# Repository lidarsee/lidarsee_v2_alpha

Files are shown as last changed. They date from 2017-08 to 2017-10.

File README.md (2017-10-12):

# LIDARsee v2 Hardware 

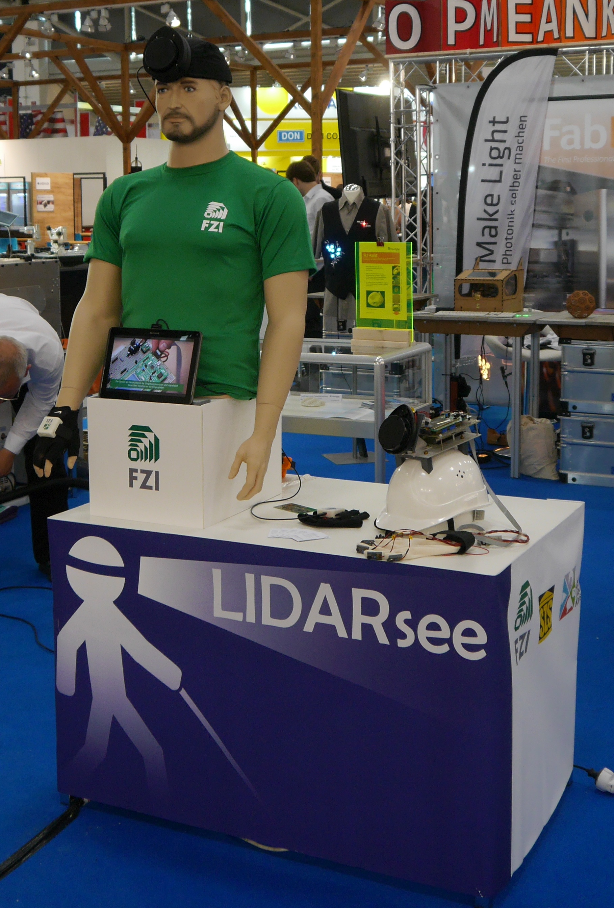
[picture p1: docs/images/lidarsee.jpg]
lidarsee


A good summary of the _Neato XV-11 LIDAR module_ can be found at:  
http://blog.tkjelectronics.dk/2014/08/handheld-xv-11-lidar-with-stm32f429-and-matlab/

## License
**Hardware license**: Creative Commons CC0
https://creativecommons.org/publicdomain/zero/1.0/legalcode

**Software license**: MIT License

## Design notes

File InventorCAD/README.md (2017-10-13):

# LIDARsee v2 Enclosure

Design is done in _Autodesk Inventor 2016_

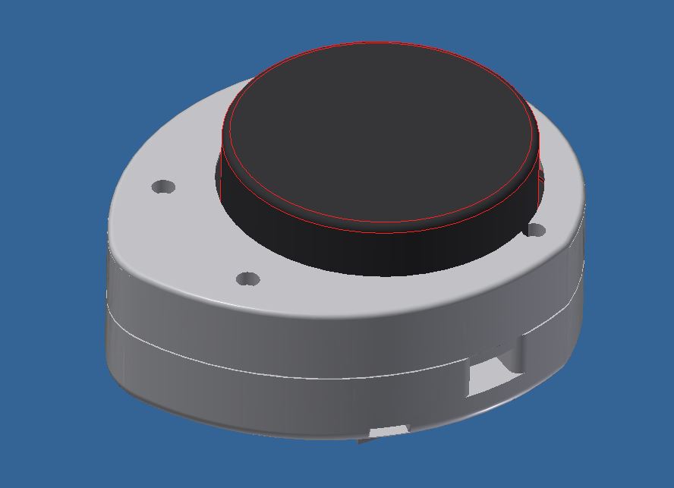
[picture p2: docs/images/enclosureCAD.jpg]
enclosure CAD


/ stp files for 3D printing, we used standard ABS and a common FDM-3D-Printer (reprap) for all parts of the construction

* _Lidarsee_v2.iam_ - main assembly
* _Lidar.ipt_ and _Lidar_v2.ipt_ are rough models of the _XV-11 LIDAR Module_
* There is also a mockup of the PCB available

## Brass Insert Nut
For the installation we used brass insert nuts which we mounted by using an old soldering iron. 

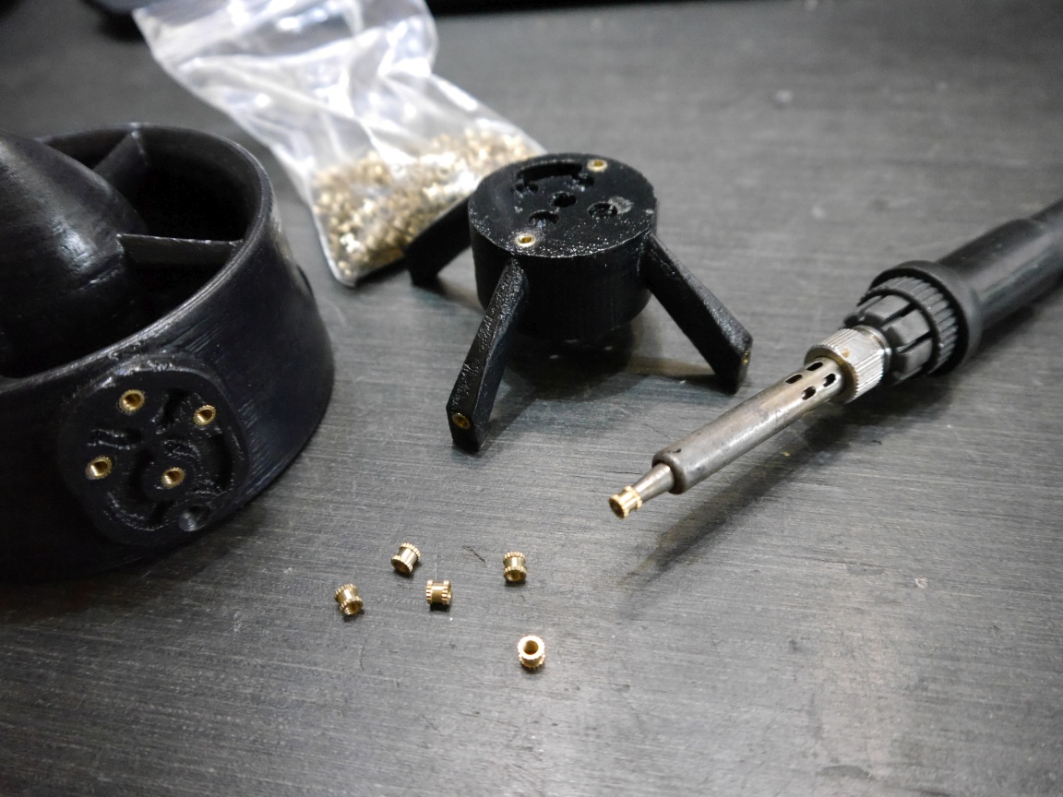
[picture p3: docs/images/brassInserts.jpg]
brassinsertnut


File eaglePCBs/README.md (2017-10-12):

# lidarsee_v2_hardware
Motherboard_STM32F405RG_r1 ist the mainboard for the head unit. 

### Features
* XV-11 lidar compatible
* STM32F405 microprocessor
* ESP32 WiFi/bluetooth-module
* Single cell lipo power supply
* MPU6050 IMU
* We used a single cell 2500mAh LiPo battery

### To Do
* Rework of the LiPo Boost converter (larger inductor?)
* IMU not tested, it is recommended to use an external IMU connected to the I2C port. Soldering the IMU by hand is quite difficult and there are a lot of cheap reliable breakout boards available. For example the BNO055 sensor also delivers easy-to-use Euler's Angles.
* Using parts that can be soldered by hand easierly

## Wiring

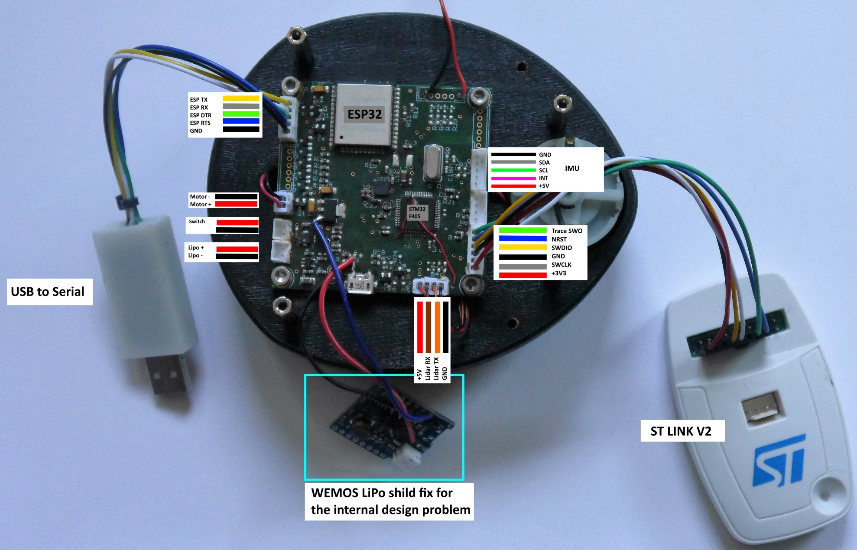
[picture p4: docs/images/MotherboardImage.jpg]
assemblyMainbaord


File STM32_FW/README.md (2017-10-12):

# lidarsee_v2_alpha STM32 Firmware

We used the _CooCox CoIDE_ for the STM32 development. A free version can be downloaded at: http://www.coocox.org/

We highly recommend to use the version 1.7.8 and _not_ to use the 2.xx beta or any 2.x Version since the compatibility is very poor. 

For programming and debugging we used a ST-Link-V2 in SWD-Mode.

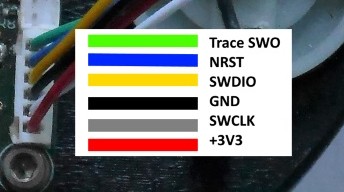
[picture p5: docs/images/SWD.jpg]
SWD


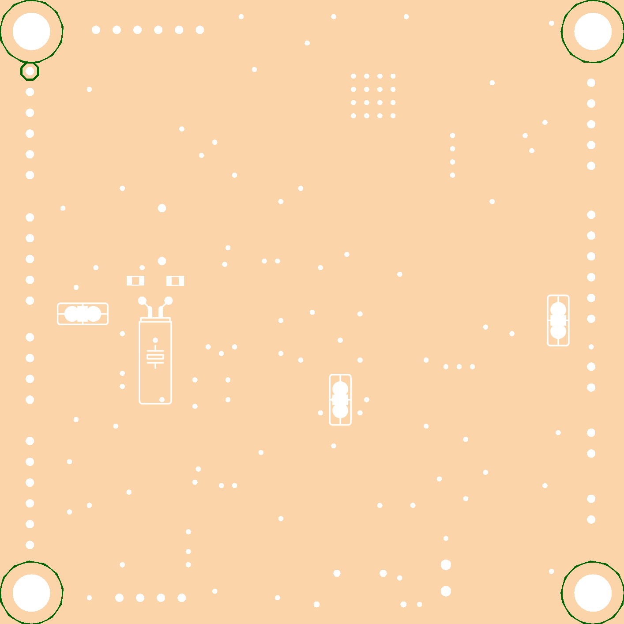
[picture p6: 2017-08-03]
InventorCAD/lidarsee/Motherboard_STM32F405RG_BOTTOM.png

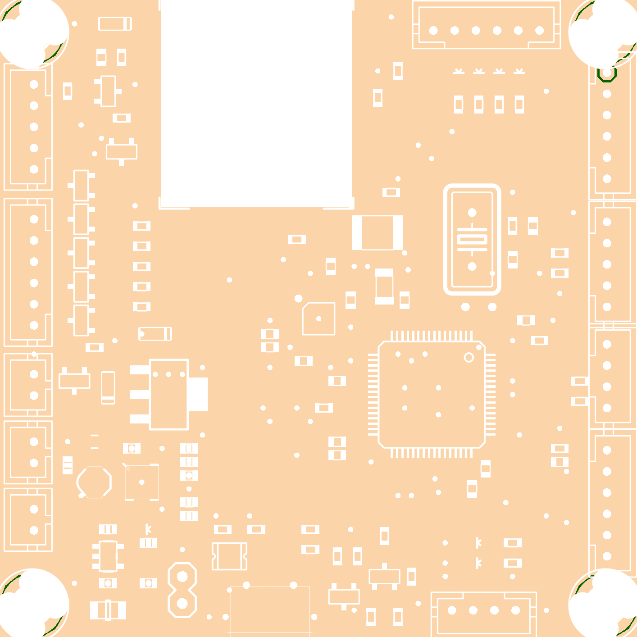
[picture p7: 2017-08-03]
InventorCAD/lidarsee/Motherboard_STM32F405RG_TOP.png

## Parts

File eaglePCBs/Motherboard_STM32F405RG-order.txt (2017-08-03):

Order list for C:/Users/ahoel/Dropbox/eagle/lidarsee/Motherboard_STM32F405RG.sch
Exported from EAGLE with DesignLink

Anzahl	Value	Package	Ordercode	Hersteller	Herstellercode	Verfügbarkeit	Preis (ab)	Beschreibung
1	10uF	1206	1288264	KEMET	C1206C106K8RACTU	13981	0.134	KEMET - C1206C106K8RACTU - KONDENSATOR, MLCC, X7R, 10UF, 10V, 1206
2	0.1uF	0603-CAP	431989	YAGEO (PHYCOMP)	CC0603MRY5V9BB104	113263	0.0076	YAGEO (PHYCOMP) - CC0603MRY5V9BB104 - KONDENSATOR, MLCC, Y5V, 100NF, 50V, 0603
1	100n	0805	1288255	KEMET	C0603C104K5RACTU	587750	0.0064	KEMET - C0603C104K5RACTU - KONDENSATOR, MLCC, X7R, 100NF, 50V, 0603
9	100n	C0603	1288255	KEMET	C0603C104K5RACTU	587750	0.0064	KEMET - C0603C104K5RACTU - KONDENSATOR, MLCC, X7R, 100NF, 50V, 0603
2	2.2µF 6.3V	C0603	1288257	KEMET	C0603C225K9PACTU	8038	0.0246	KEMET - C0603C225K9PACTU - KONDENSATOR, MLCC, X5R, 2.2UF, 6.3V 0603
2	4.7uF	0603-CAP	1572625	KEMET	C0603C475K8PACTU	55850	0.0523	KEMET - C0603C475K8PACTU - KONDENSATOR, MLCC, X5R, 4.7UF, 10V, 0603
1	10u 10V	C1206	1288264	KEMET	C1206C106K8RACTU	13981	0.134	KEMET - C1206C106K8RACTU - KONDENSATOR, MLCC, X7R, 10UF, 10V, 1206
2	27p	C0603	722017	YAGEO (PHYCOMP)	CC0603JRNPO9BN270	13342	0.0072	YAGEO (PHYCOMP) - CC0603JRNPO9BN270 - KONDENSATOR MLCC C0G/NP0 27PF 50V 0603
2	10p	C0603	317202	AVX	06035A102JAT2A	125356	0.0107	AVX - 06035A102JAT2A - KONDENSATOR, MLCC, C0G/NP0, 1NF 50V 0603
1	1µ	C0603	1658870	AVX	0603YC105KAT2A	27884	0.018	AVX - 0603YC105KAT2A - KONDENSATOR, MLCC, X7R, 1UF, 16V, 0603
1	10n	C0603	722236	YAGEO (PHYCOMP)	CC0603KRX7R9BB103	34686	0.0066	YAGEO (PHYCOMP) - CC0603KRX7R9BB103 - KONDENSATOR, MLCC, X7R, 10NF, 50V, 0603
3	33µF	A/3216-18W	2333095	AVX	TPSA336M006R0600	3018	0.193	AVX - TPSA336M006R0600 - TANTALKONDENSATOR, 33UF, 6.3V, BAUFORM A
1	2.2n	C0603	722194	YAGEO (PHYCOMP)	CC0603KRX7R9BB222	7636	0.0083	YAGEO (PHYCOMP) - CC0603KRX7R9BB222 - KONDENSATOR, MLCC, X7R, 2.2NF, 50V, 0603
7	red	LED-0603	1226390	OSRAM	LSQ976-Z	15931	0.0358	OSRAM - LSQ976-Z - LED, SMD ROT
1	1210L010	1210L	1822206	LITTELFUSE	1210L010WR	5849	0.172	LITTELFUSE - 1210L010WR - SICHERUNG, PTC, 1210, 0.1A
4	MOUNT-PAD-ROUND3.6	3,6-PAD	unknown					
1	STM32F40X	LQFP64	2064363	STMICROELECTRONICS	STM32F405RGT6	9718	6.18	STMICROELECTRONICS - STM32F405RGT6 - IC,MCU, 32BIT, 1MB FLASH, 64LQFP
1	LD1117ASTR	SOT223	1652366	ON SEMICONDUCTOR	NCP1117ST33T3G	6296	0.127	ON SEMICONDUCTOR - NCP1117ST33T3G - LINEARSPANNUNGSREGLER
1	IN	1X02	9491856	JST (JAPAN SOLDERLESS TERMINALS)	B2B-PH-K-S(LF)(SN)	446666	0.0581	JST (JAPAN SOLDERLESS TERMINALS) - B2B-PH-K-S(LF)(SN) - STECKER,OBEN EING,2KONT
1	4.7uH, 1.2A	CDRH2D09	2219271	MURATA	LQH3NPN4R7MJ0L	838	0.106	MURATA - LQH3NPN4R7MJ0L - LEISTUNGSINDUKTIVITÄT, 4.7UH, +/-30%
1		L1812	unknown					
2		JST-PH4	9492437	JST (JAPAN SOLDERLESS TERMINALS)	B4B-PH-K-S(LF)(SN)	145775	0.0844	JST (JAPAN SOLDERLESS TERMINALS) - B4B-PH-K-S(LF)(SN) - STECKER,OBEN EING,4KONT
2	JST-PH5	JST-PH5	9492445	JST (JAPAN SOLDERLESS TERMINALS)	B5B-PH-K-S(LF)(SN)	37245	0.105	JST (JAPAN SOLDERLESS TERMINALS) - B5B-PH-K-S(LF)(SN) - STECKER,OBEN EING,5KONT
4		JST-PH6	9492453	JST (JAPAN SOLDERLESS TERMINALS)	B6B-PH-K-S(LF)(SN)	120187	0.121	JST (JAPAN SOLDERLESS TERMINALS) - B6B-PH-K-S(LF)(SN) - STECKER,OBEN EING,6KONT
3		JST-PH2	9491856	JST (JAPAN SOLDERLESS TERMINALS)	B2B-PH-K-S(LF)(SN)	446666	0.0581	JST (JAPAN SOLDERLESS TERMINALS) - B2B-PH-K-S(LF)(SN) - STECKER,OBEN EING,2KONT
6	IRLML6344	SOT23	1857299	INFINEON	IRLML6344TRPBF	37543	0.104	INFINEON - IRLML6344TRPBF - MOSFET, N-KANAL, 30V, 5A, SOT23
1	8MHz	HC18U-V	1666997	MULTICOMP	HC49S-8-30-50-70-30-ATF	7738	0.228	MULTICOMP - HC49S-8-30-50-70-30-ATF - QUARZ, HC-49/S, 8.0MHZ
1	32768	TC38H	1457085	CITIZEN FINETECH MIYOTA	CFS206 32.768KDZB-UB	18815	0.113	CITIZEN FINETECH MIYOTA - CFS206 32.768KDZB-UB - QUARZ, UHR, 32.768KHZ, ZYLINDER, 6PF
1	1.2M	0603-RES	2073340	MULTICOMP	MCMR06W2004FTL	6247	0.0029	MULTICOMP - MCMR06W2004FTL - KERAMIKWIDERSTAND, 2M, 1%, 0.1W, 0603
1	10k	0603-RES	2073349	MULTICOMP	MCMR06X1002FTL	70119	0.0027	MULTICOMP - MCMR06X1002FTL - KERAMIKWIDERSTAND, 10K, 1%, 0.1W, 0603
1	2M	0603-RES	1811595	KOA SPEER ELECTRONICS	RK73H1JTTD1204F	6769	0.0134	KOA SPEER ELECTRONICS - RK73H1JTTD1204F - DICKSCHICHTWIDERSTAND 1M2 1% 0.1W 0603
2	220k	0603-RES	1576314	MULTICOMP	MCHP03W8F2203T5E	57056	0.0059	MULTICOMP - MCHP03W8F2203T5E - DICKSCHICHTWIDERST. 220K 1% 0.125W 0603
1	2k	0603-RES	9238522	YAGEO (PHYCOMP)	RC0603FR-072K2L.	90932	0.0040	YAGEO (PHYCOMP) - RC0603FR-072K2L. - DICKSCHICHTWIDERSTAND 2K2 1% 0.1W 0603
14	10	R0603	1469751	VISHAY	CRCW060310R0FKEA	93997	0.0055	VISHAY - CRCW060310R0FKEA - DICKSCHICHTWIDERSTAND 10R 1% 0.1W 0603
1	470	0603-RES	1576273	MULTICOMP	MCHP03W8F4700T5E	19878	0.0057	MULTICOMP - MCHP03W8F4700T5E - DICKSCHICHTWIDERST. 470R 1% 0.125W 0603
1	1M	R0603	1469746	VISHAY	CRCW06031M00FKEA	65750	0.0055	VISHAY - CRCW06031M00FKEA - DICKSCHICHTWIDERSTAND 1M 1% 0.1W 0603
3	22	R0603	1469781	VISHAY	CRCW060322R0FKEA	11239	0.0055	VISHAY - CRCW060322R0FKEA - DICKSCHICHTWIDERSTAND 22R 1% 0.1W 0603
5	33k	R0603	1469801	VISHAY	CRCW060333K0FKEA	14795	0.0055	VISHAY - CRCW060333K0FKEA - DICKSCHICHTWIDERSTAND 33K 1% 0.1W 0603
1	10k	R0603	2073349	MULTICOMP	MCMR06X1002FTL	70119	0.0027	MULTICOMP - MCMR06X1002FTL - KERAMIKWIDERSTAND, 10K, 1%, 0.1W, 0603
1	1k5	R0603	2073391	MULTICOMP	MCMR06X1501FTL	5289	0.0027	MULTICOMP - MCMR06X1501FTL - KERAMIKWIDERSTAND, 1K5, 1%, 0.1W, 0603
1	1k	R0603	1469740	VISHAY	CRCW06031K00FKEA	230207	0.0055	VISHAY - CRCW06031K00FKEA - DICKSCHICHTWIDERSTAND 1K 1% 0.1W 0603
1	47k	R0603	1469811	VISHAY	CRCW060347K0FKEA	12994	0.0055	VISHAY - CRCW060347K0FKEA - DICKSCHICHTWIDERSTAND 47K 1% 0.1W 0603
1	15k	R0603	1469758	VISHAY	CRCW060315K0FKEA	21335	0.0055	VISHAY - CRCW060315K0FKEA - DICKSCHICHTWIDERSTAND 15K 1% 0.1W 0603
1	22k	R0603	1527541	TE CONNECTIVITY / NEOHM	CPF0603F4K22C1	995	0.0192	TE CONNECTIVITY / NEOHM - CPF0603F4K22C1 - DÜNNSCHICHTWIDERST. 4K22 1% 0.063W 0603
8	12k	R0603	1170832	MULTICOMP	MC0063W060312K8	53482	0.0020	MULTICOMP - MC0063W060312K8 - DICKSCHICHTWIDERSTAND 2K8 1% 0.063W 0603
3		SJ_2	unknown					
4		SOT23-BEC	1081223	NEXPERIA	BC817,215	24559	0.019	NEXPERIA - BC817,215 - TRANSISTOR, NPN, 45V, SOT-23
1	MPU-9250	LEAD-QFN24	1864742	INVENSENSE	MPU-6050	2496	5.65	INVENSENSE - MPU-6050 - GYRO/BESCHL.MESSER, 6ACHSEN, I2C, QFN-24
1	MICRO-USB-RECEPTACLE47589-0001	47589-0001	1568023	MOLEX	47589-0001	8109	0.315	MOLEX - 47589-0001 - MICRO-USB-2.0-BUCHSE, TYP AB, SMD
1	ESP-WROOM-03	ESP-WROOM-03	unknown					
1	MCP73831	SOT23-5	1332158	MICROCHIP	MCP73831T-2ACI/OT	28596	0.394	MICROCHIP - MCP73831T-2ACI/OT - LI-ION/LI-POLY LADE CONTROLLER
1	TPS61200	QFN-10_PAD	1471238	TEXAS INSTRUMENTS	TPS61200DRCT	412	1.87	TEXAS INSTRUMENTS - TPS61200DRCT - WANDLER,BOOST SYNCH, 1.5A, SMD

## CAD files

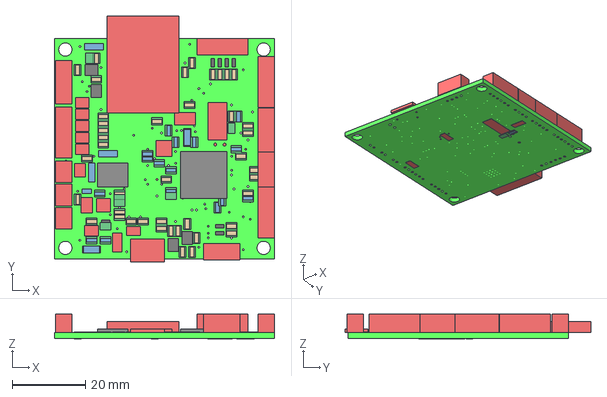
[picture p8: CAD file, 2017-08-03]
InventorCAD/lidarsee/Motherboard_STM32F405RG_simpel.STEP
60.0 x 67.0 x 6.67 mm

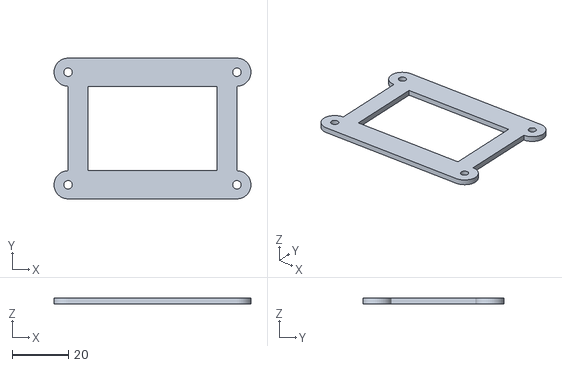
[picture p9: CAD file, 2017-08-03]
InventorCAD/lidarsee/stl/templateMount_0.stl
70.0 x 50.0 x 2.00

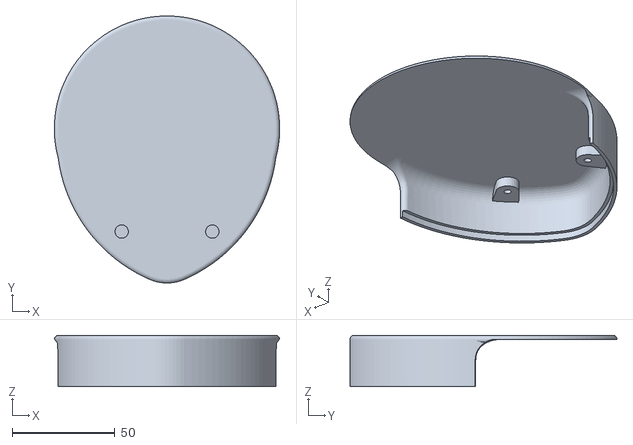
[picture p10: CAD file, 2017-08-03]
InventorCAD/lidarsee/stl/LidarseeCase_C_0.stl
109.5 x 129.7 x 25.0

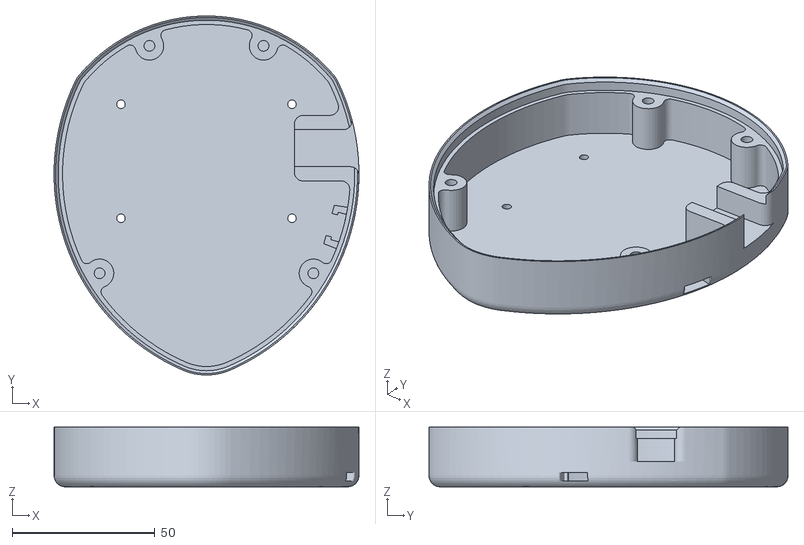
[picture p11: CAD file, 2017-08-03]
InventorCAD/lidarsee/stl/LidarseeCase_v2_C_0.stl
107.0 x 126.0 x 21.0

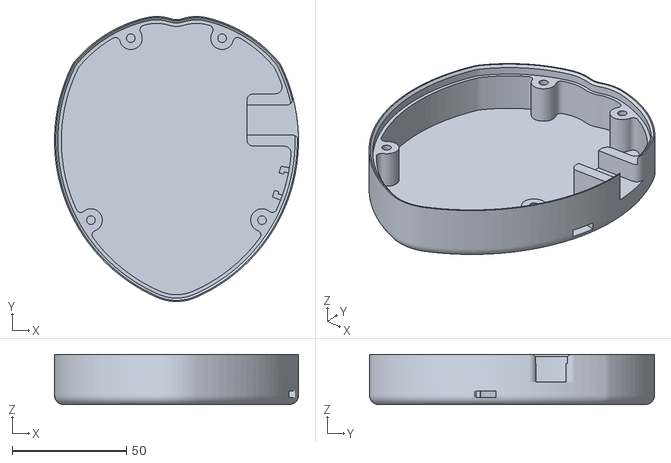
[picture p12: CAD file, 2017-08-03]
InventorCAD/lidarsee/stl/LidarseeCase_B_0.stl
107.0 x 125.0 x 22.0

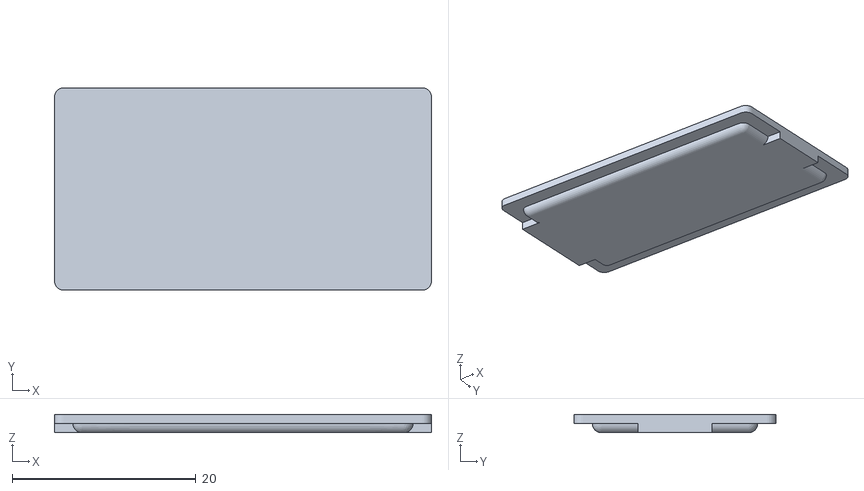
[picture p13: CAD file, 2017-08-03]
InventorCAD/lidarsee/stl/USB_case_B_0.stl
41.0 x 22.0 x 2.00

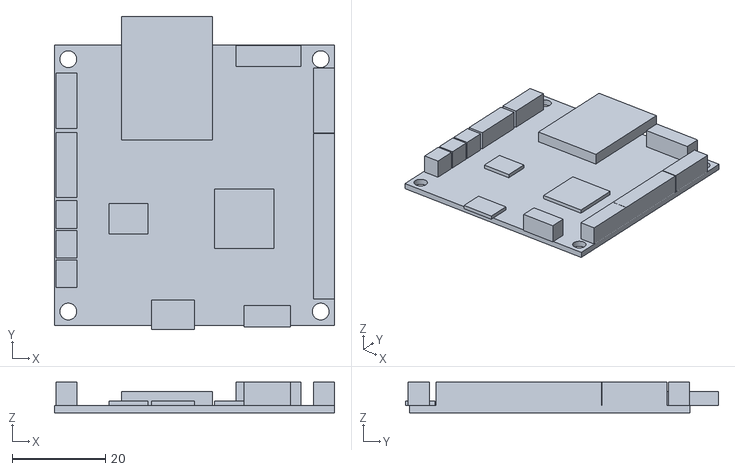
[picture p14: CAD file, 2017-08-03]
InventorCAD/lidarsee/stl/Motherboard_STM32F405RG_simpel_0.stl
60.0 x 67.0 x 6.57

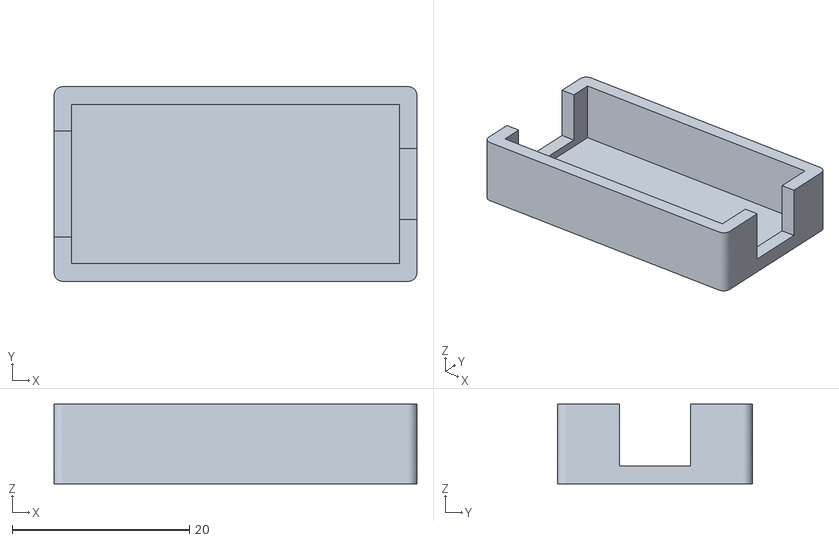
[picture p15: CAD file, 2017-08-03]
InventorCAD/lidarsee/stl/USB_case_A_0.stl
41.0 x 22.0 x 9.00

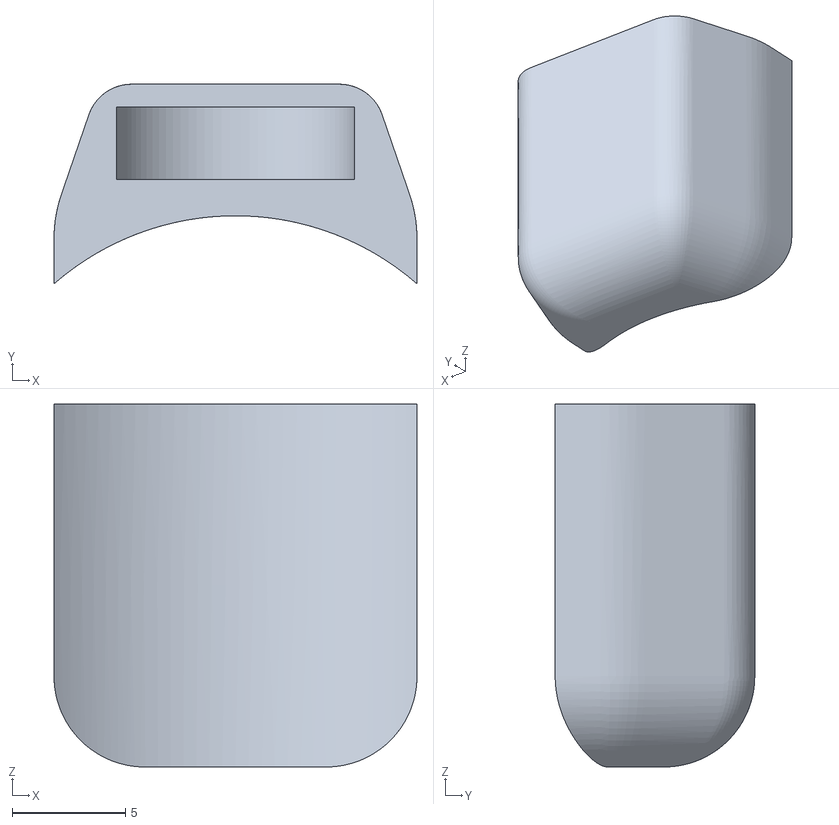
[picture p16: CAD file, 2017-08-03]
InventorCAD/lidarsee/stl/vibramount_v2_0.stl
16.0 x 8.80 x 16.0

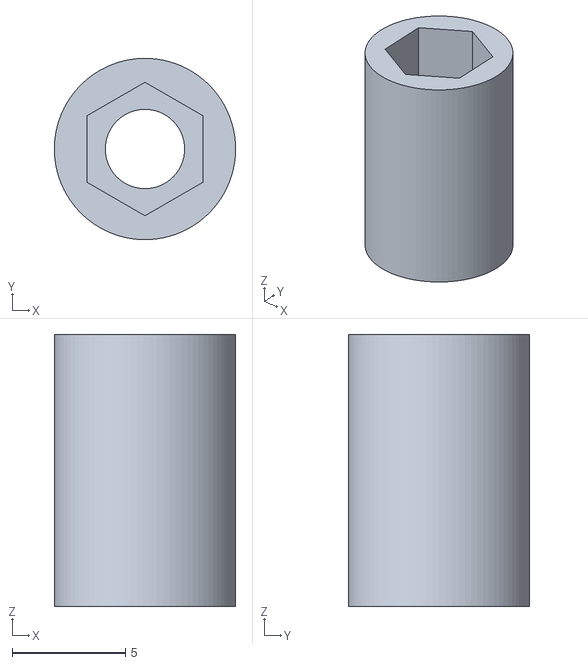
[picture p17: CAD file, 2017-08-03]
InventorCAD/lidarsee/stl/8mm_spacer_0.stl
8.00 x 8.00 x 12.0

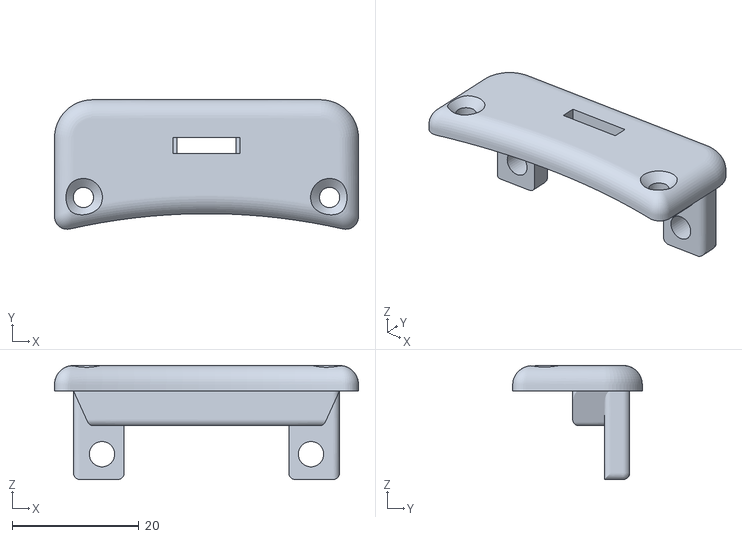
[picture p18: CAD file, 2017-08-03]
InventorCAD/lidarsee/stl/handschuhCase_0.stl
48.0 x 20.5 x 18.0

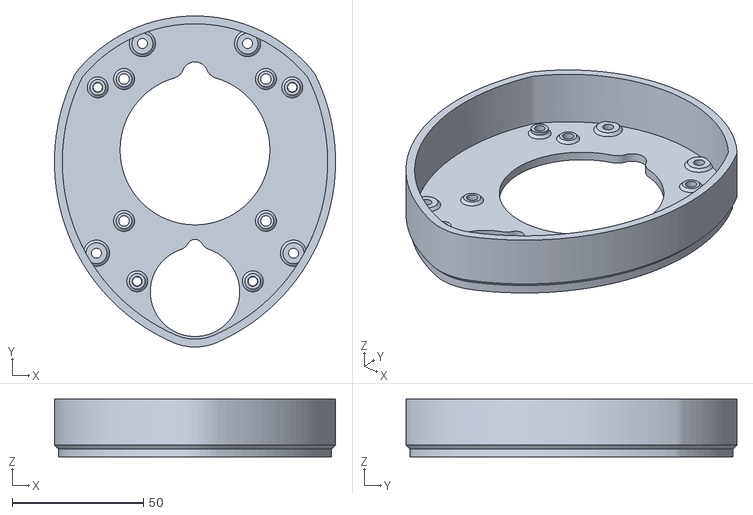
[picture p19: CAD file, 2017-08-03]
InventorCAD/lidarsee/stl/LidarseeCase_v2_A_0.stl
107.0 x 126.0 x 22.0

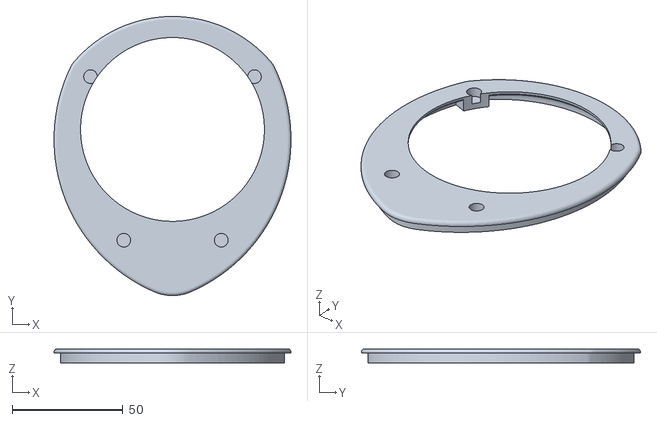
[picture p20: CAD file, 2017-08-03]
InventorCAD/lidarsee/stl/LidarseeCase_v2_B_0.stl
107.0 x 126.0 x 6.50

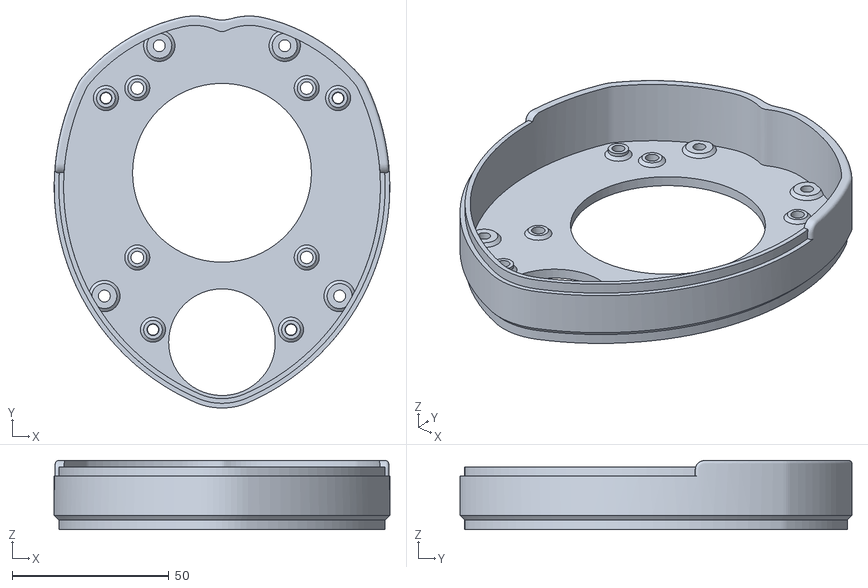
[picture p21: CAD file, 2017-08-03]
InventorCAD/lidarsee/stl/LidarseeCase_A_0.stl
107.0 x 125.0 x 22.0

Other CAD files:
InventorCAD/lidarsee/stl/Mount_0.stl
InventorCAD/lidarsee/8mm spacer.ipt
InventorCAD/lidarsee/Lidar.ipt
InventorCAD/lidarsee/Lidar_v2.ipt
InventorCAD/lidarsee/Lidarsee.iam
InventorCAD/lidarsee/LidarseeCase_A.ipt
InventorCAD/lidarsee/LidarseeCase_B.ipt
InventorCAD/lidarsee/LidarseeCase_C.ipt
InventorCAD/lidarsee/LidarseeCase_v2_A.ipt
InventorCAD/lidarsee/LidarseeCase_v2_B.ipt
InventorCAD/lidarsee/LidarseeCase_v2_C.ipt
InventorCAD/lidarsee/Lidarsee_v2.iam
InventorCAD/lidarsee/Mainboard.ipt
InventorCAD/lidarsee/Motherboard_STM32F405RG_simpel.ipt
InventorCAD/lidarsee/Mount.ipt
InventorCAD/lidarsee/Mount_2.ipt
InventorCAD/lidarsee/USB_case_A.ipt
InventorCAD/lidarsee/USB_case_B.ipt
InventorCAD/lidarsee/handschuhCase.ipt
InventorCAD/lidarsee/idearsee_v2.idw
InventorCAD/lidarsee/templateMount.ipt
InventorCAD/lidarsee/vibramount.ipt
InventorCAD/lidarsee/vibramount_v2.ipt

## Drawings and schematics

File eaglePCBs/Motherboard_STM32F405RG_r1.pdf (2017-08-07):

# 12k GND MOUNT-PAD-ROUND3.6

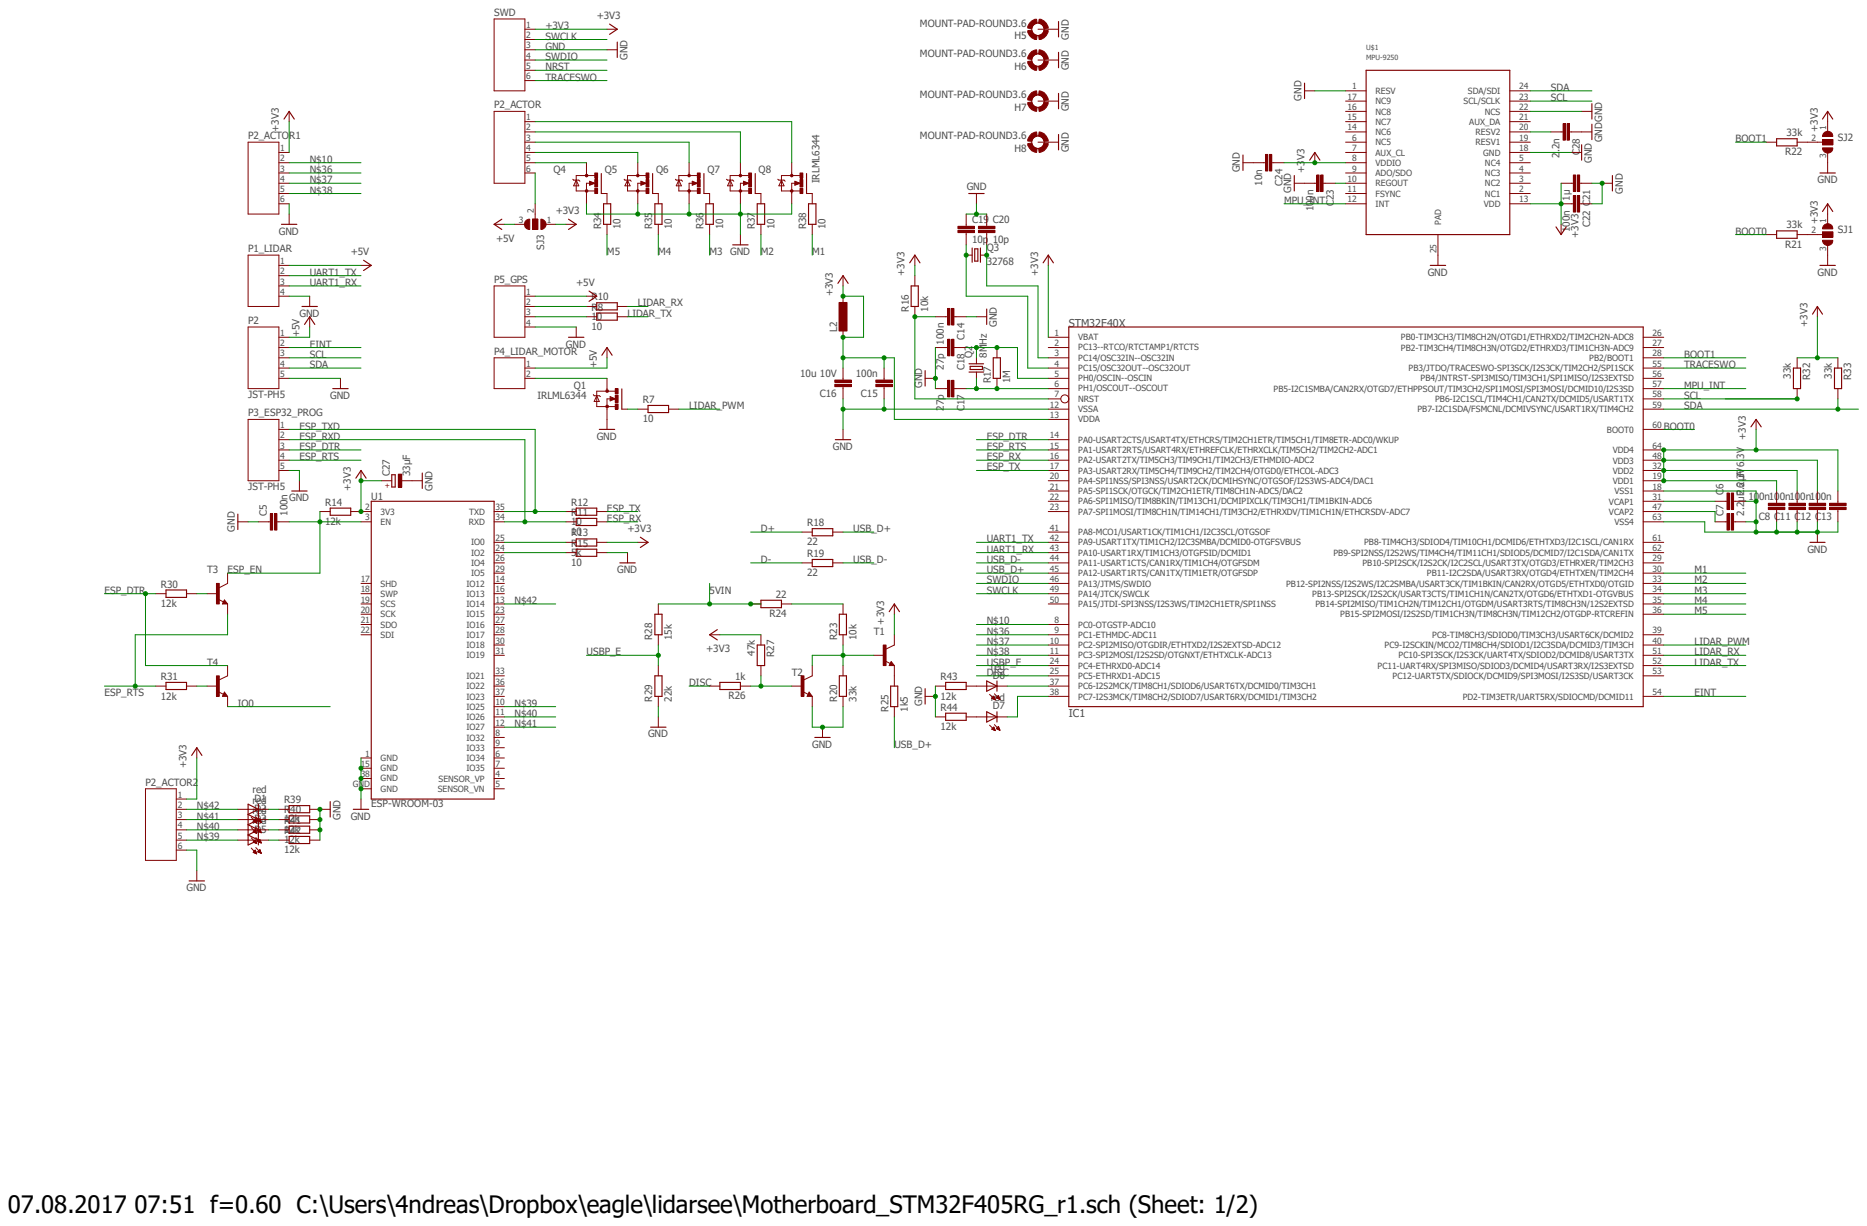
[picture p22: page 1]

07.08.2017 07:51 f=0.60 C:\Users\4ndreas\Dropbox\eagle\lidarsee\Motherboard_STM32F405RG_r1.sch (Sheet: 1/2)

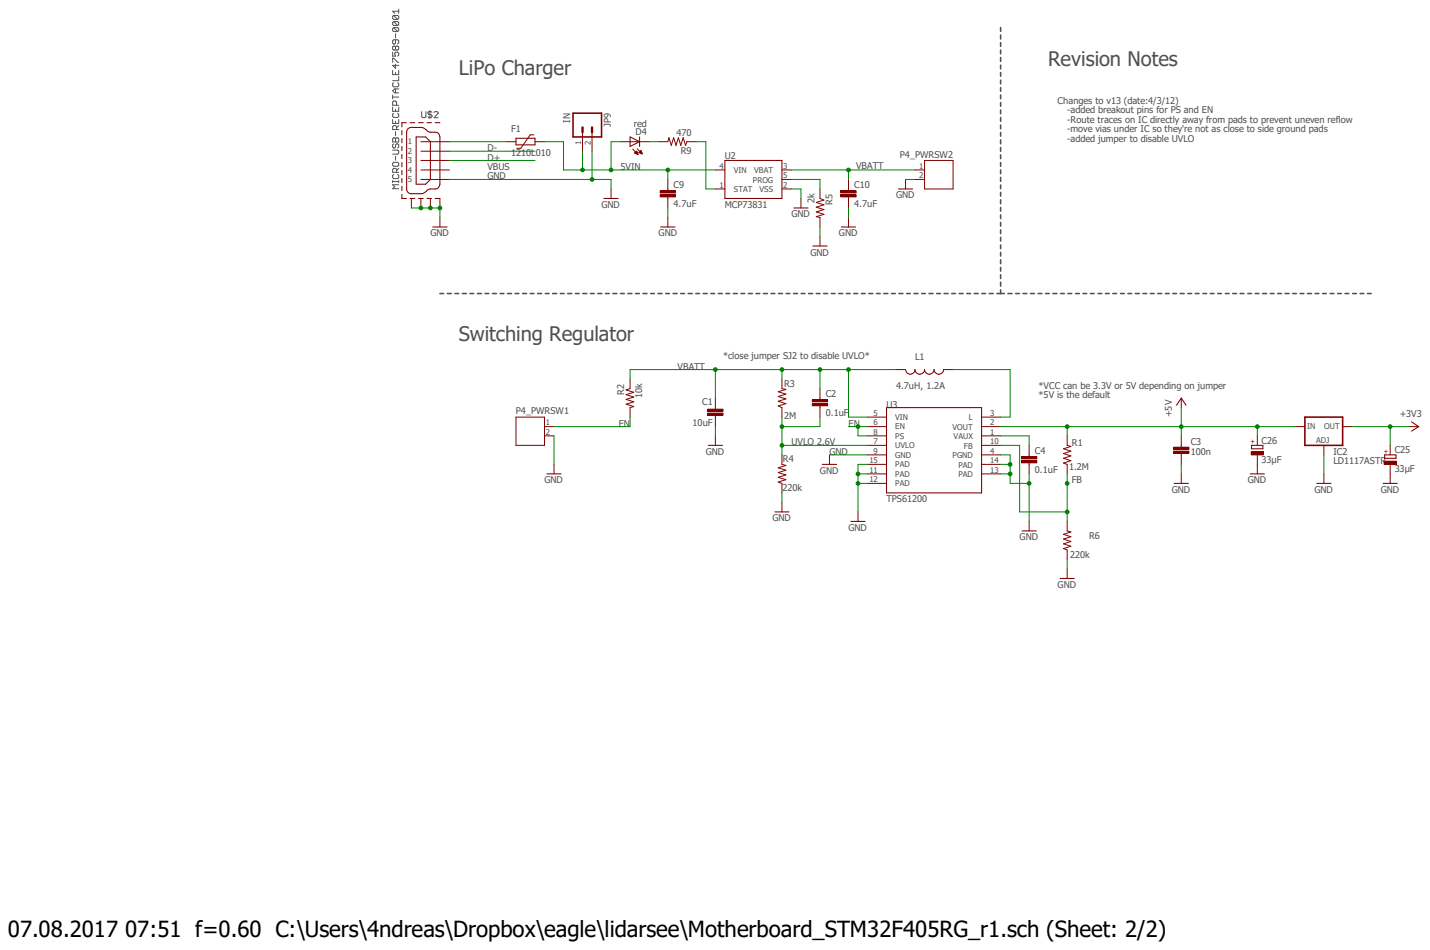
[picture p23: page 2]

-added jumper to disable UVLO LiPo Charger

Changes to v13 (date:4/3/12)
-added breakout pins for PS and EN
-Route traces on IC directly away from pads to prevent uneven reflow
-move vias under IC so they're not as close to side ground pads

*close jumper SJ2 to disable UVLO*

*VCC can be 3.3V or 5V depending on jumper
*5V is the default

07.08.2017 07:51 f=0.60 C:\Users\4ndreas\Dropbox\eagle\lidarsee\Motherboard_STM32F405RG_r1.sch (Sheet: 2/2)

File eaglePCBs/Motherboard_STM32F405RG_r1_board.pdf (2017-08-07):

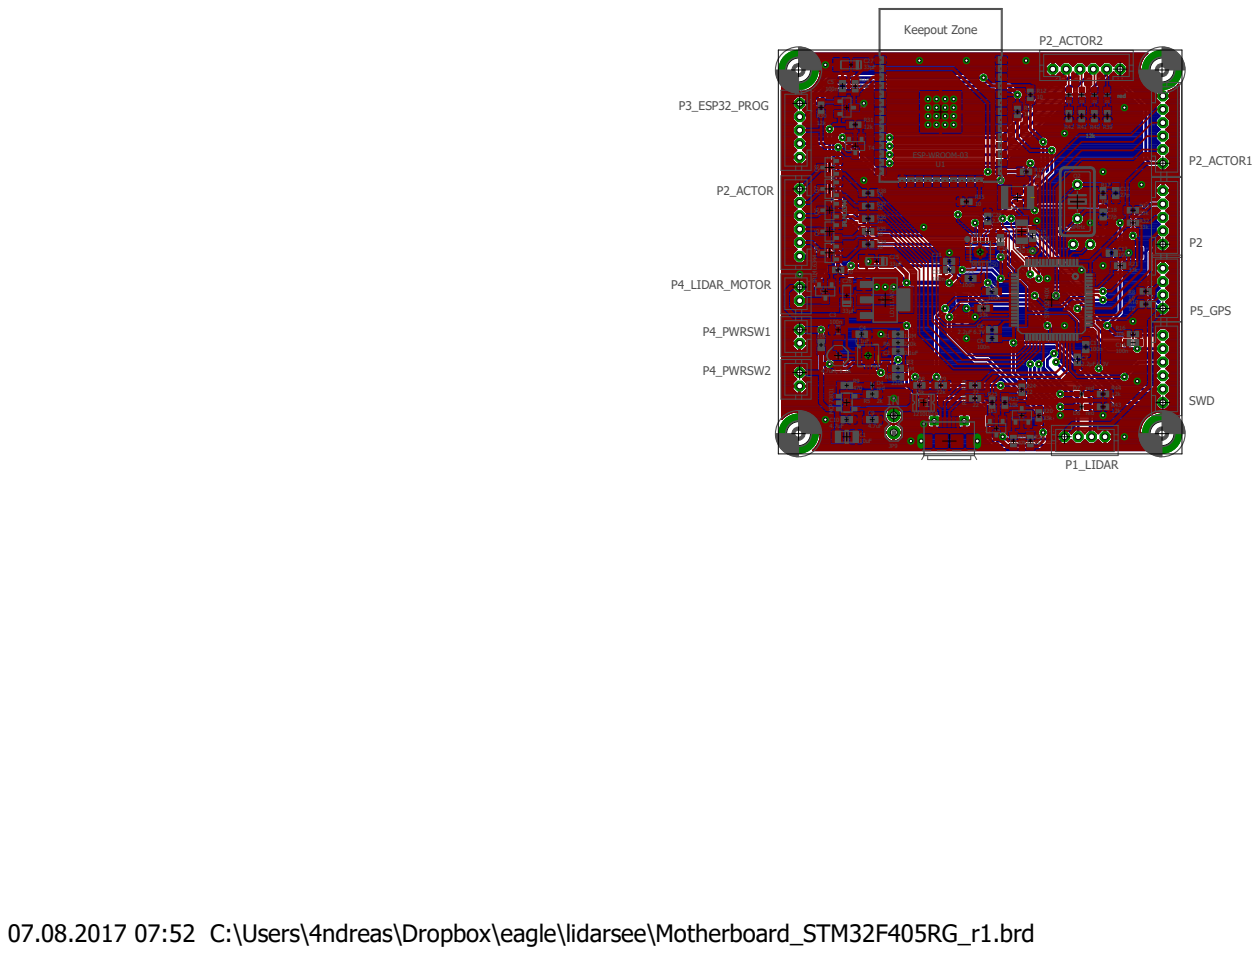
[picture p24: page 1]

C4 R1 1.2M 220k 0.1uF | R3 | 2.2µF 6.3V R16
0.1uF R6 | C8 C11
C2 L1 | C7 2.2µF 6.3V

07.08.2017 07:52 C:\Users\4ndreas\Dropbox\eagle\lidarsee\Motherboard_STM32F405RG_r1.brd

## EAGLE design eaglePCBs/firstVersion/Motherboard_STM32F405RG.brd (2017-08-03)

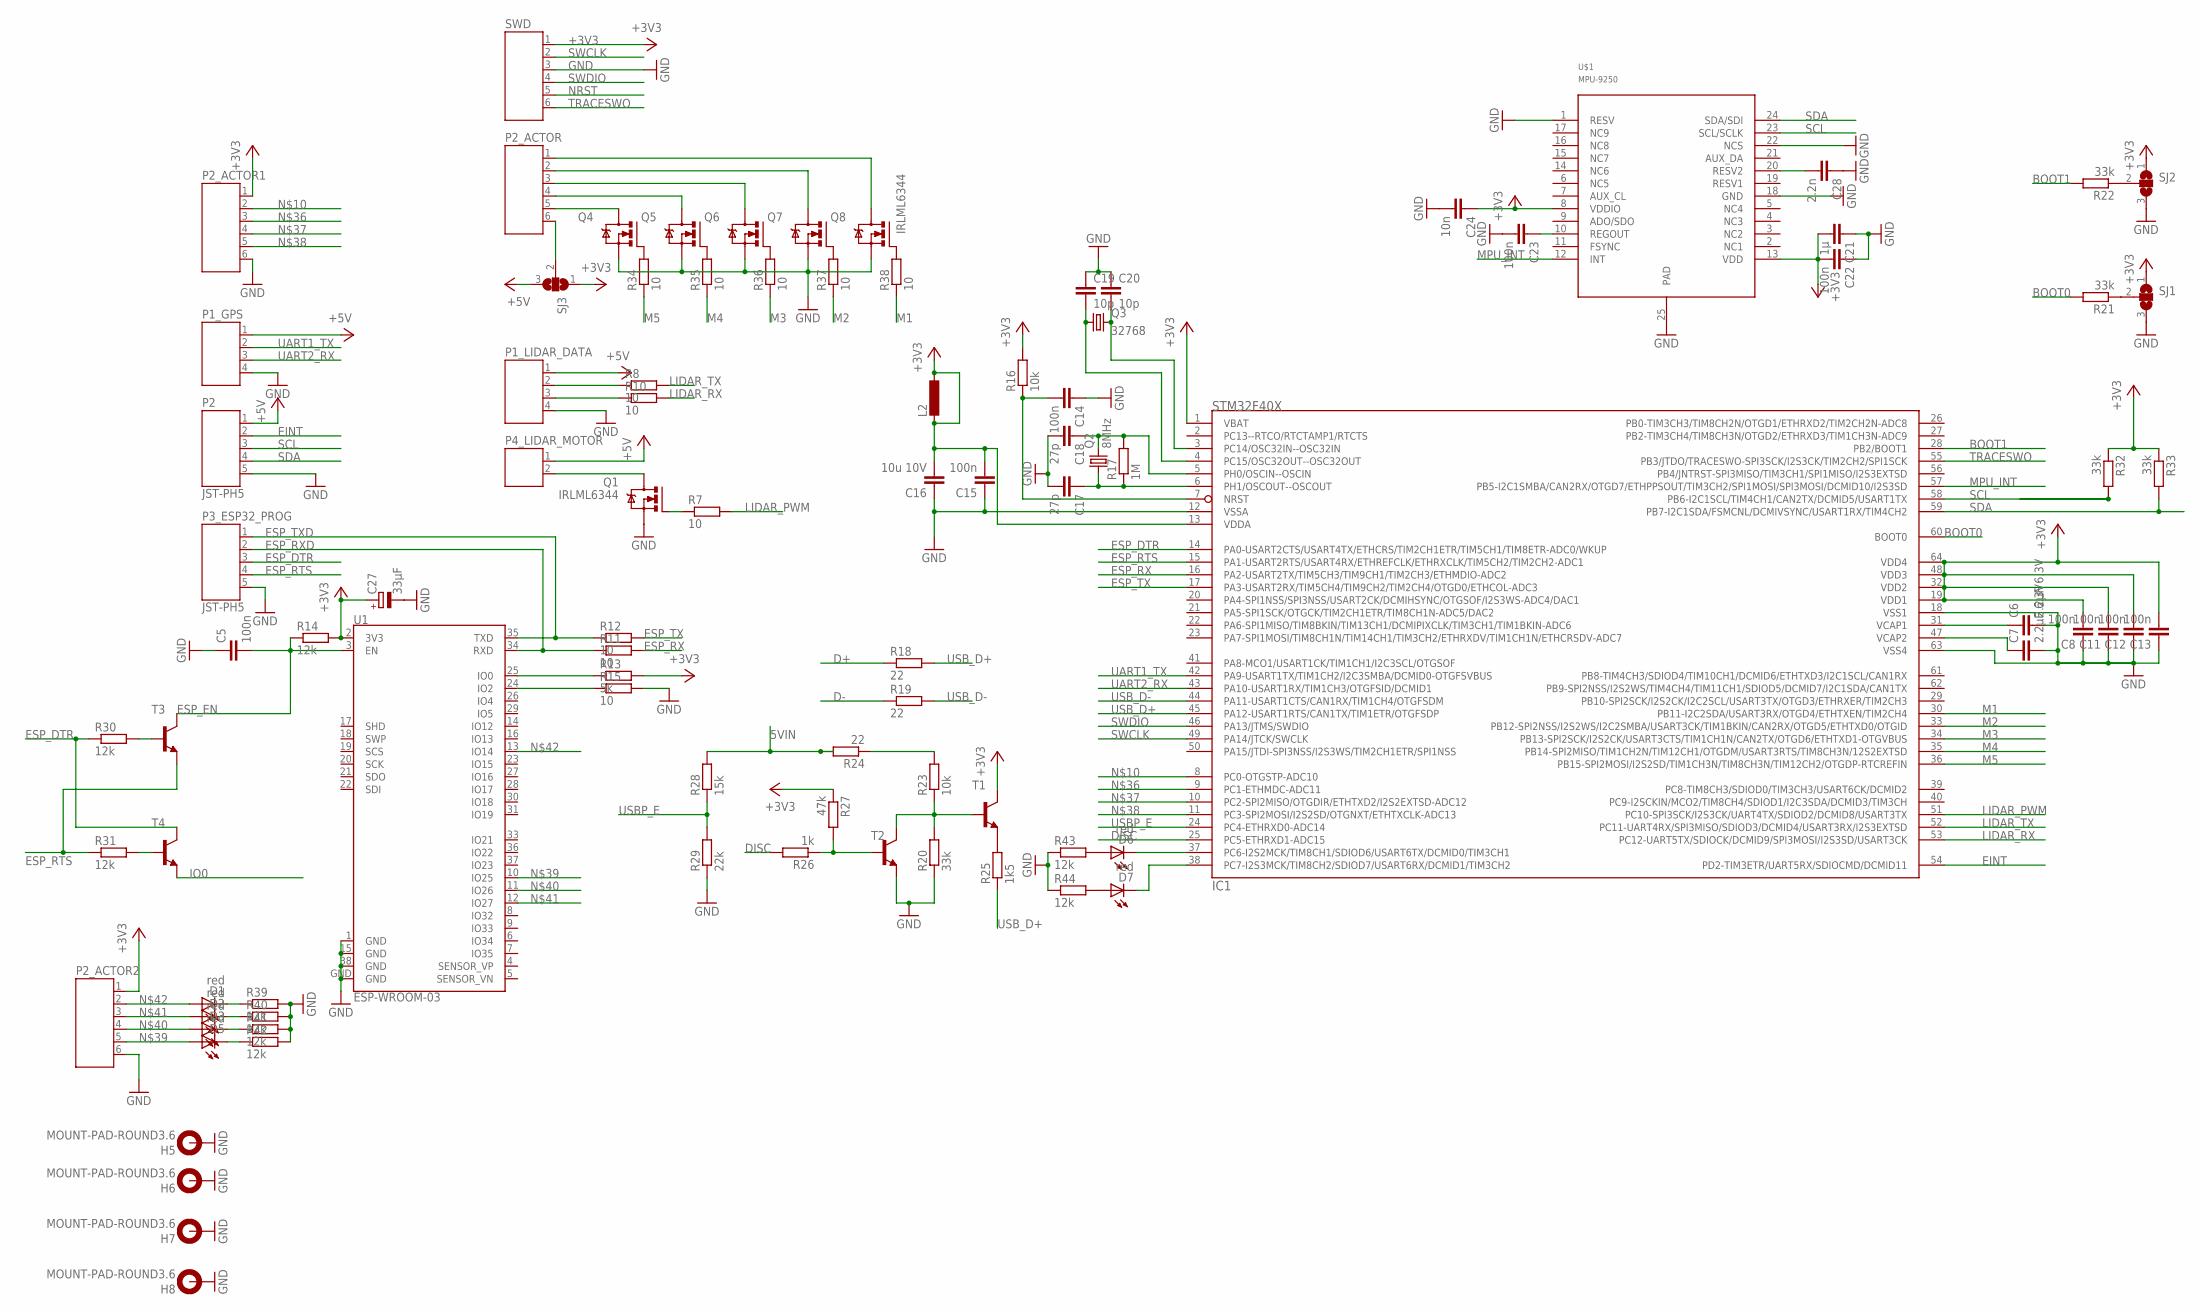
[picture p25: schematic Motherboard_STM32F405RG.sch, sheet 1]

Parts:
C5, C8, C11, C12, C13, C14, C15, C22, C23: 100n; C0603; MPN C0603C104K5RACTU
C6, C7: 2.2µF 6.3V; C0603; MPN C0603C225K9PACTU
C16: 10u 10V; C1206; MPN C1206C106K8RACTU
C17, C18: 27p; C0603; MPN CC0603JRNPO9BN270
C19, C20: 10p; C0603; MPN 06035A102JAT2A
C21: 1µ; C0603; MPN 0603YC105KAT2A
C24: 10n; C0603; MPN CC0603KRX7R9BB103
C27: 33µF; A/3216-18W; MPN TPSA336M006R0600
C28: 2.2n; C0603; MPN CC0603KRX7R9BB222
D1, D2, D3, D5, D6, D7: red; LED-0603; MPN LSQ976-Z
H5, H6, H7, H8: MOUNT-PAD-ROUND3.6; 3,6-PAD
IC1: STM32F40X; LQFP64; MPN STM32F405RGT6
L2: L-EUL1812; L1812
P1_GPS, P1_LIDAR_DATA: JST-PH4; MPN B4B-PH-K-S(LF)(SN)
P2, P3_ESP32_PROG: JST-PH5; MPN B5B-PH-K-S(LF)(SN)
P2_ACTOR, P2_ACTOR1, P2_ACTOR2: JST-PH6; MPN B6B-PH-K-S(LF)(SN)
P4_LIDAR_MOTOR: JST-PH2; MPN B2B-PH-K-S(LF)(SN)
Q1, Q4, Q5, Q6, Q7, Q8: IRLML6344; SOT23; MPN IRLML6344TRPBF
Q2: 8MHz; HC18U-V; MPN HC49S-8-30-50-70-30-ATF
Q3: 32768; TC38H; MPN CFS206 32.768KDZB-UB
R7, R8, R10, R11, R12, R15, R34, R35, R36, R37, R38: 10; R0603; MPN CRCW060310R0FKEA
R13: 5k; R0603; MPN CRCW060310R0FKEA
R14: 12k; R0603; MPN CRCW060310R0FKEA
R16: 10k; R0603; MPN CRCW060310R0FKEA
R17: 1M; R0603; MPN CRCW06031M00FKEA
R18, R19, R24: 22; R0603; MPN CRCW060322R0FKEA
R20, R21, R22, R32, R33: 33k; R0603; MPN CRCW060333K0FKEA
R23: 10k; R0603; MPN MCMR06X1002FTL
R25: 1k5; R0603; MPN MCMR06X1501FTL
R26: 1k; R0603; MPN CRCW06031K00FKEA
R27: 47k; R0603; MPN CRCW060347K0FKEA
R28: 15k; R0603; MPN CRCW060315K0FKEA
R29: 22k; R0603; MPN CPF0603F4K22C1
R30, R31, R39, R40, R41, R42, R43, R44: 12k; R0603; MPN MC0063W060312K8
SJ1, SJ2, SJ3: SJ2W; SJ_2
SWD: JST-PH6; MPN B6B-PH-K-S(LF)(SN)
T1, T2, T3, T4: BC817-16-NPN-SOT23-BEC; SOT23-BEC; MPN BC817,215
U1: ESP-WROOM-03
U$1: MPU-9250; LEAD-QFN24; MPN MPU-6050

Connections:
5VIN: R24.2, R28.2; also elsewhere on the board
+3V3: C8.2, C11.2, C12.2, C13.2, C15.2, C16.2, C21.2, C22.2, C24.1, C27.+, IC1.1 (VBAT), IC1.13 (VDDA), IC1.19 (VDD1), IC1.32 (VDD2), IC1.48 (VDD3), IC1.64 (VDD4), L2.1, L2.2, P2_ACTOR1.1, P2_ACTOR2.1, R13.2, R14.2, R16.2, R27.1, R32.1, R33.1, SJ1.1, SJ2.1, SJ3.1, SWD.1, T1.C, U1.2 (3V3), U$1.8 (VDDIO), U$1.13 (VDD); also elsewhere on the board
+5V: P1_GPS.1, P1_LIDAR_DATA.1, P2.1, P4_LIDAR_MOTOR.1, SJ3.3; also elsewhere on the board
BOOT0: IC1.60 (BOOT0), R21.2
BOOT1: IC1.28 (PB2/BOOT1), R22.2
D+: R18.1; also elsewhere on the board
D-: R19.1; also elsewhere on the board
DISC: IC1.25 (PC5-ETHRXD1-ADC15), R26.2
EINT: IC1.54 (PD2-TIM3ETR/UART5RX/SDIOCMD/DCMID11), P2.2
ESP_DTR: IC1.14 (PA0-USART2CTS/USART4TX/ETHCRS/TIM2CH1ET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), P3_ESP32_PROG.3, R30.1, T4.C
ESP_EN: C5.2, R14.1, T3.C, U1.3 (EN)
ESP_RTS: IC1.15 (PA1-USART2RTS/USART4RX/ETHREFCLK/ETHRXC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), P3_ESP32_PROG.4, R31.1, T3.E
ESP_RX: IC1.16 (PA2-USART2TX/TIM5CH3/TIM9CH1/TIM2CH3/ET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), R11.2
ESP_RXD: P3_ESP32_PROG.2, R11.1, U1.34 (RXD)
ESP_TX: IC1.17 (PA3-USART2RX/TIM5CH4/TIM9CH2/TIM2CH4/OT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), R12.2
ESP_TXD: P3_ESP32_PROG.1, R12.1, U1.35 (TXD)
GND: C5.1, C6.2, C7.2, C8.1, C11.1, C12.1, C13.1, C14.1, C15.1, C16.1, C17.2, C18.2, C19.1, C20.1, C21.1, C22.1, C23.2, C24.2, C27.-, C28.1, H5.B3,6, H6.B3,6, H7.B3,6, H8.B3,6, IC1.12 (VSSA), IC1.18 (VSS1), IC1.63 (VSS4), P1_GPS.4, P1_LIDAR_DATA.4, P2.5, P2_ACTOR1.6, P2_ACTOR2.6, P3_ESP32_PROG.5, Q1.2 (S), Q4.2 (S), Q5.2 (S), Q6.2 (S), Q7.2 (S), Q8.2 (S), R15.2, R20.1, R29.1, R39.2, R40.2, R41.2, R42.2, R43.1, R44.1, SJ1.3, SJ2.3, SWD.3, T2.E, U1.1 (GND), U1.15 (GND), U1.38 (GND), U1.GND, U$1.1 (RESV), U$1.18 (GND), U$1.22 (NCS), U$1.25 (PAD); also elsewhere on the board
IO0: R13.1, T4.E, U1.25 (IO0)
IO2: R15.1, U1.24 (IO2)
LIDAR_PWM: IC1.51 (PC10-SPI3SCK/I2S3CK/UART4TX/SDIOD2/DCMI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), R7.2
LIDAR_RX: IC1.53 (PC12-UART5TX/SDIOCK/DCMID9/SPI3MOSI/I2S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), R10.2
LIDAR_TX: IC1.52 (PC11-UART4RX/SPI3MISO/SDIOD3/DCMID4/USA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), R8.2
M1: IC1.30 (PB11-I2C2SDA/USART3RX/OTGD4/ETHTXEN/TIM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), R38.1
M2: IC1.33 (PB12-SPI2NSS/I2S2WS/I2C2SMBA/USART3CK/T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), R37.1
M3: IC1.34 (PB13-SPI2SCK/I2S2CK/USART3CTS/TIM1CH1N/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), R36.1
M4: IC1.35 (PB14-SPI2MISO/TIM1CH2N/TIM12CH1/OTGDM/U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), R35.1
M5: IC1.36 (PB15-SPI2MOSI/I2S2SD/TIM1CH3N/TIM8CH3N/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), R34.1
MPU_INT: IC1.57 (PB5-I2C1SMBA/CAN2RX/OTGD7/ETHPPSOUT/TIM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), U$1.12 (INT)
unnamed: C28.2, U$1.20 (RESV2)
unnamed: P4_LIDAR_MOTOR.2, Q1.3 (D)
unnamed: Q1.1 (G), R7.1
unnamed: P1_LIDAR_DATA.2, R8.1
unnamed: P1_LIDAR_DATA.3, R10.1
unnamed: C23.1, U$1.10 (REGOUT)
unnamed: IC1.8 (PC0-OTGSTP-ADC10), P2_ACTOR1.2
unnamed: P2_ACTOR.5, Q4.3 (D)
unnamed: R31.2, T4.B
unnamed: P2_ACTOR.4, Q5.3 (D)
unnamed: C17.1, IC1.6 (PH1/OSCOUT--OSCOUT), Q2.1, R17.1
unnamed: P2_ACTOR.3, Q6.3 (D)
unnamed: P2_ACTOR.2, Q7.3 (D)
unnamed: C18.1, IC1.5 (PH0/OSCIN--OSCIN), Q2.2, R17.2
unnamed: C19.2, IC1.4 (PC15/OSC32OUT--OSC32OUT), Q3.1
unnamed: C20.2, IC1.3 (PC14/OSC32IN--OSC32IN), Q3.2
unnamed: R20.2, R23.1, T1.B, T2.C
unnamed: R21.1, SJ1.2
unnamed: R22.1, SJ2.2
unnamed: P2_ACTOR.1, Q8.3 (D)
unnamed: R25.2, T1.E
unnamed: R23.2, R24.1
unnamed: R26.1, R27.2, T2.B
unnamed: R30.2, T3.B
unnamed: P2_ACTOR.6, SJ3.2
unnamed: Q4.1 (G), R34.2
unnamed: Q5.1 (G), R35.2
unnamed: Q6.1 (G), R36.2
unnamed: Q7.1 (G), R37.2
unnamed: Q8.1 (G), R38.2
unnamed: IC1.9 (PC1-ETHMDC-ADC11), P2_ACTOR1.3
unnamed: IC1.10 (PC2-SPI2MISO/OTGDIR/ETHTXD2/I2S2EXTSD-A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), P2_ACTOR1.4
unnamed: IC1.11 (PC3-SPI2MOSI/I2S2SD/OTGNXT/ETHTXCLK-ADC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), P2_ACTOR1.5
unnamed: D5.A, P2_ACTOR2.5, U1.10 (IO25)
unnamed: D3.A, P2_ACTOR2.4, U1.11 (IO26)
unnamed: D2.A, P2_ACTOR2.3, U1.12 (IO27)
unnamed: D1.A, P2_ACTOR2.2, U1.13 (IO14)
unnamed: D1.C, R39.1
unnamed: D2.C, R40.1
unnamed: D3.C, R41.1
unnamed: D5.C, R42.1
unnamed: D6.C, IC1.37 (PC6-I2S2MCK/TIM8CH1/SDIOD6/USART6TX/DCM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)
unnamed: D7.C, IC1.38 (PC7-I2S3MCK/TIM8CH2/SDIOD7/USART6RX/DCM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)
unnamed: D6.A, R43.2
unnamed: D7.A, R44.2
NRST: C14.2, IC1.7 (NRST), R16.1, SWD.5
SCL: IC1.58 (PB6-I2C1SCL/TIM4CH1/CAN2TX/DCMID5/USART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), P2.3, R32.2, U$1.23 (SCL/SCLK)
SDA: IC1.59 (PB7-I2C1SDA/FSMCNL/DCMIVSYNC/USART1RX/T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), P2.4, R33.2, U$1.24 (SDA/SDI)
SWCLK: IC1.49 (PA14/JTCK/SWCLK), SWD.2
SWDIO: IC1.46 (PA13/JTMS/SWDIO), SWD.4
TRACESWO: IC1.55 (PB3/JTDO/TRACESWO-SPI3SCK/I2S3CK/TIM2CH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), SWD.6
UART1_TX: IC1.42 (PA9-USART1TX/TIM1CH2/I2C3SMBA/DCMID0-OT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), P1_GPS.2
UART2_RX: IC1.43 (PA10-USART1RX/TIM1CH3/OTGFSID/DCMID1), P1_GPS.3
USBP_E: IC1.24 (PC4-ETHRXD0-ADC14), R28.1, R29.2
USB_D+: IC1.45 (PA12-USART1RTS/CAN1TX/TIM1ETR/OTGFSDP), R18.2, R25.1
USB_D-: IC1.44 (PA11-USART1CTS/CAN1RX/TIM1CH4/OTGFSDM), R19.2
VCAP1: C6.1, IC1.31 (VCAP1)
VCAP2: C7.1, IC1.47 (VCAP2)

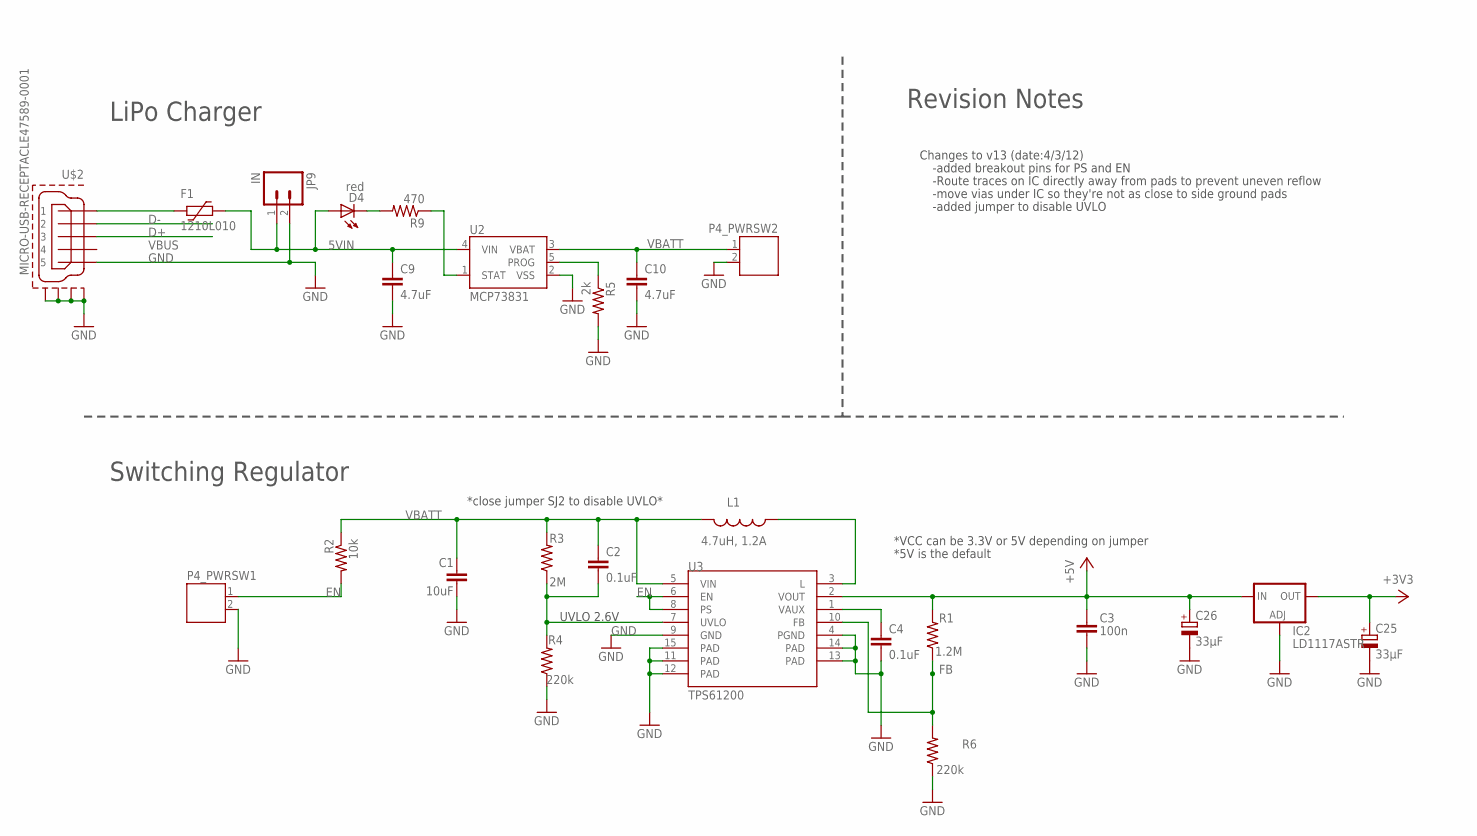
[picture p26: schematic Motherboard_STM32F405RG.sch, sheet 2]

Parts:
C1: 10uF; 1206; MPN C1206C106K8RACTU
C2, C4: 0.1uF; 0603-CAP; MPN CC0603MRY5V9BB104
C3: 100n; 0805; MPN C0603C104K5RACTU
C9, C10: 4.7uF; 0603-CAP; MPN C0603C475K8PACTU
C25, C26: 33µF; A/3216-18W; MPN TPSA336M006R0600
D4: red; LED-0603; MPN LSQ976-Z
F1: 1210L010; 1210L; MPN 1210L010WR
IC2: LD1117ASTR; SOT223; MPN NCP1117ST33T3G
JP9: IN; 1X02; MPN B2B-PH-K-S(LF)(SN)
L1: 4.7uH, 1.2A; CDRH2D09; MPN LQH3NPN4R7MJ0L
P4_PWRSW1, P4_PWRSW2: JST-PH2; MPN B2B-PH-K-S(LF)(SN)
R1: 1.2M; 0603-RES; MPN MCMR06W2004FTL
R2: 10k; 0603-RES; MPN MCMR06X1002FTL
R3: 2M; 0603-RES; MPN RK73H1JTTD1204F
R4, R6: 220k; 0603-RES; MPN MCHP03W8F2203T5E
R5: 2k; 0603-RES; MPN RC0603FR-072K2L.
R9: 470; 0603-RES; MPN MCHP03W8F4700T5E
U2: MCP73831; SOT23-5; MPN MCP73831T-2ACI/OT
U3: TPS61200; QFN-10_PAD; MPN TPS61200DRCT
U$2: MICRO-USB-RECEPTACLE47589-0001; 47589-0001; MPN 47589-0001

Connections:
5VIN: C9.1, D4.A, F1.1, JP9.1, U2.4 (VIN); also elsewhere on the board
+3V3: C25.+, IC2.2 (OUT), IC2.4 (OUT); also elsewhere on the board
+5V: C3.1, C26.+, IC2.3 (IN), R1.2, U3.2 (VOUT); also elsewhere on the board
D+: U$2.3; also elsewhere on the board
D-: U$2.2; also elsewhere on the board
EN: P4_PWRSW1.1, R2.2, U3.6 (EN), U3.8 (PS)
FB: R1.1, R6.2, U3.10 (FB)
GND: C1.2, C3.2, C4.2, C9.2, C10.2, C25.-, C26.-, IC2.1 (ADJ), JP9.2, P4_PWRSW1.2, P4_PWRSW2.2, R4.1, R5.2, R6.1, U2.2 (VSS), U3.4 (PGND), U3.9 (GND), U3.11 (PAD), U3.12 (PAD), U3.13 (PAD), U3.14 (PAD), U3.15 (PAD), U$2.5, U$2.CASING1 (GND1), U$2.CASING2 (GND2), U$2.CASING3 (GND3), U$2.CASING4 (GND4); also elsewhere on the board
unnamed: C4.1, U3.1 (VAUX)
unnamed: L1.P$1 (1), U3.3 (L)
unnamed: D4.C, R9.2
unnamed: R5.1, U2.5 (PROG)
unnamed: R9.1, U2.1 (STAT)
UVLO: C2.2, R3.1, R4.2, U3.7 (UVLO)
VBATT: C1.1, C2.1, C10.1, L1.P$2 (2), P4_PWRSW2.1, R2.1, R3.2, U2.3 (VBAT), U3.5 (VIN)
VBUS: F1.2, U$2.1

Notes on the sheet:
UVLO 2.6V
Changes to v13 (date:4/3/12)
-added breakout pins for PS and EN
-Route traces on IC directly away from pads to prevent uneven reflow
-move vias under IC so they're not as close to side ground pads
*close jumper SJ2 to disable UVLO*
-added jumper to disable UVLO
LiPo Charger
Switching Regulator
Revision Notes
*VCC can be 3.3V or 5V depending on jumper
*5V is the default

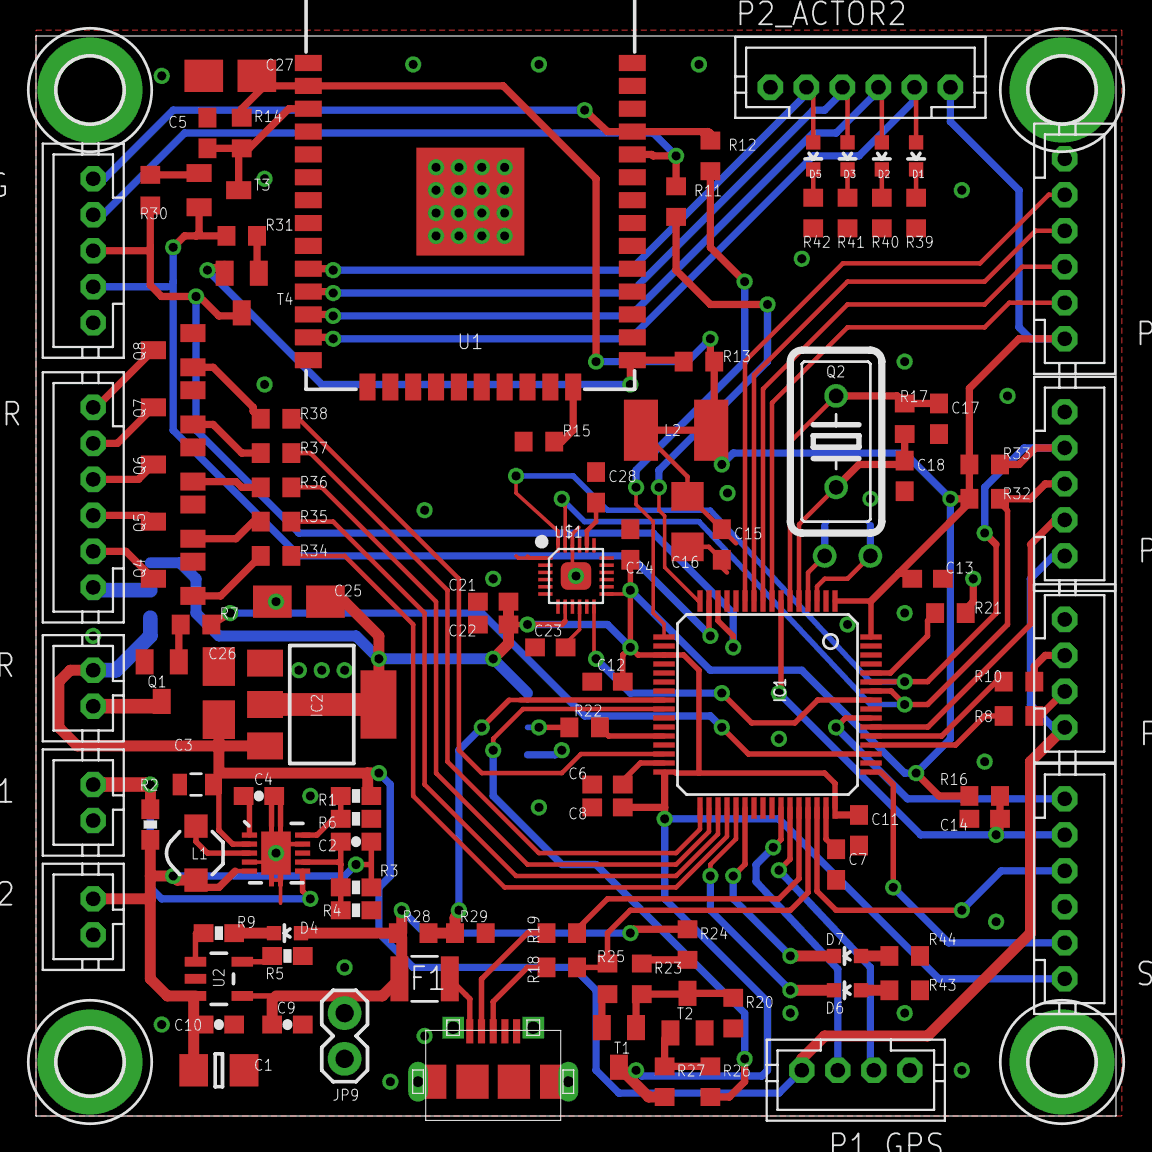
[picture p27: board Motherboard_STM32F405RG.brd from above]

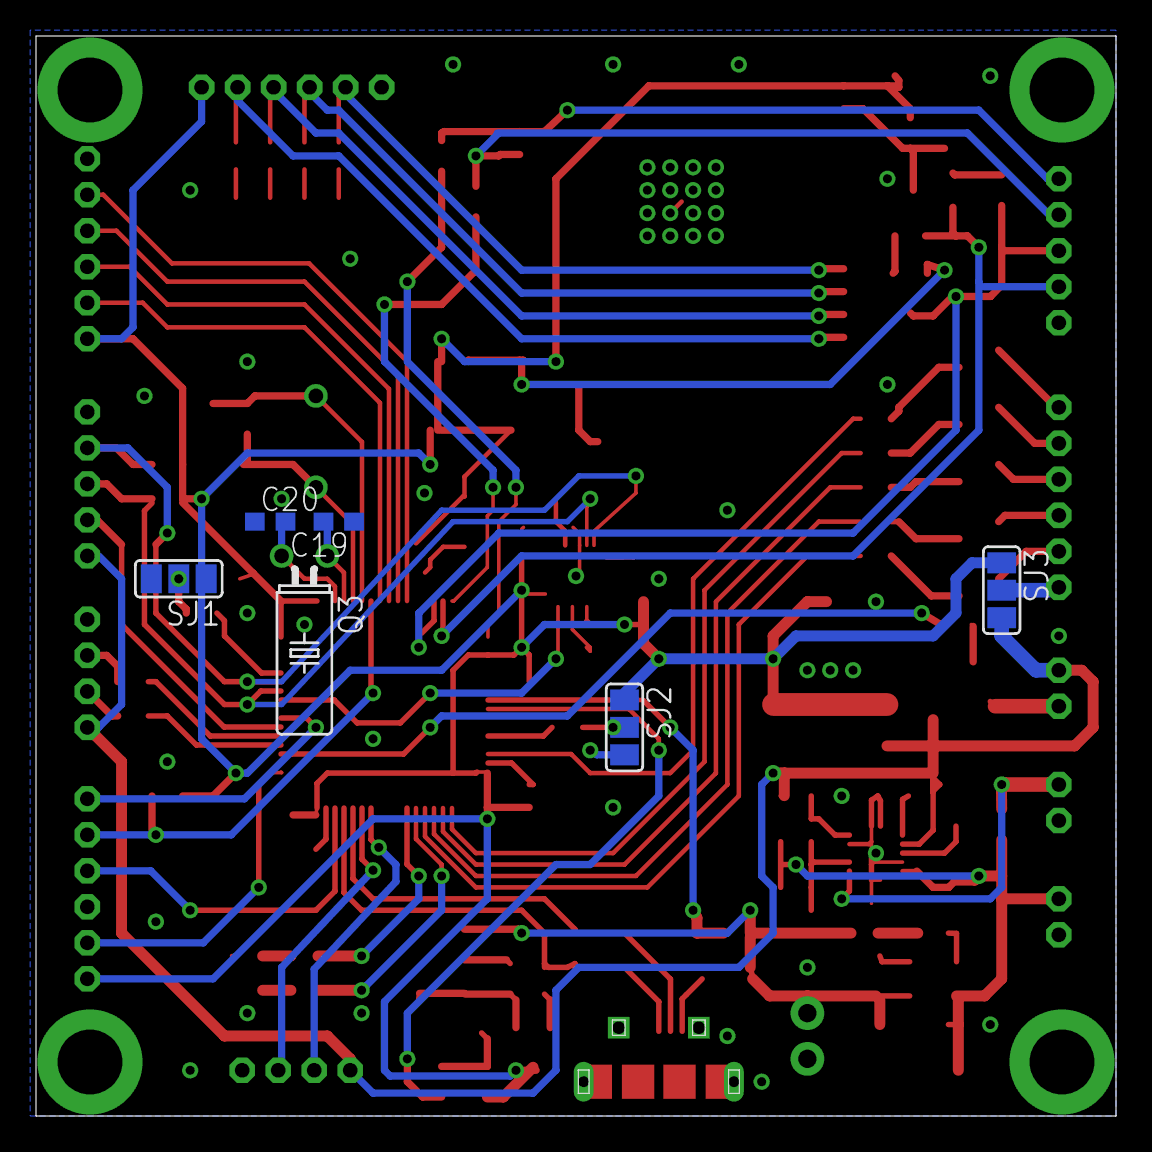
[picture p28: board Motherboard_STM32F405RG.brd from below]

Board: 2 copper layers, 60.0 x 60.0 mm, 120 parts (6 on the bottom side), 96 nets.

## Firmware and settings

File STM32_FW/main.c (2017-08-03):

#include "stm32f4xx.h"
#include "stm32f4xx_rcc.h"
#include "math.h"
#include "string.h"
#include "Serial.h"
#include "Serial2.h"
#include "Delay.h"


#define XV11_PACKAGE_LENGTH	22
#define XV11_START_BYTE	0xFA


// Functions
uint16_t PackageChecksum(uint8_t * packagePointer);


// Global Variables
uint16_t GoodReadings = 0, BadReadings = 0;
uint16_t AnglesCovered = 0;

uint8_t XV11_Package[22];

uint16_t Distance[360];
uint32_t PrintTimestamp;
uint32_t DisplayTimestamp;




int main(void)
{
	RCC_ClocksTypeDef RCC_Clocks;

	RCC_GetClocksFreq(&RCC_Clocks);
	SysTick_Config(RCC_Clocks.SYSCLK_Frequency / 1000);


	Serial_Init();
	Serial2_Init();

	SyncUp();

    while(1)
    {
    	//SH_SendChar('2');
    	//Serial_WriteByte(0xBB);
    	//Serial2_WriteByte(0x0A);

	while (Serial_Buffer_Count() < XV11_PACKAGE_LENGTH);
		LoadPackage(XV11_Package);
		if (XV11_Package[0] != XV11_START_BYTE) {
			SyncUp();
		} else {
			ParsePackage(XV11_Package);

			Serial2_WriteByte(0xAA);
			Serial2_WriteByte(0xBB);
			Serial2_WriteByte(0xCC);
			Serial2_WriteWords(Distance, 360);
			Serial2_WriteByte(0xCC);
			Serial2_WriteByte(0xBB);
			Serial2_WriteByte(0xAA);
		}


    }
}

void ParsePackage(uint8_t * packagePointer)
{
uint16_t i;
uint16_t Index;
uint8_t Speed;
uint8_t InvalidFlag[4];
uint8_t WarningFlag[4];
uint16_t Checksum, ChecksumCalculated;

Checksum = ((uint16_t)packagePointer[21] << 8) | packagePointer[20];
ChecksumCalculated = PackageChecksum(packagePointer);
if (Checksum != ChecksumCalculated) {
	BadReadings += 4;
}

Index = (packagePointer[1] - 0xA0) * 4;
Speed = ((uint16_t)packagePointer[3] << 8) | packagePointer[2];
InvalidFlag[0] = (packagePointer[5] & 0x80) >> 7;
InvalidFlag[1] = (packagePointer[9] & 0x80) >> 7;
InvalidFlag[2] = (packagePointer[13] & 0x80) >> 7;
InvalidFlag[3] = (packagePointer[17] & 0x80) >> 7;
WarningFlag[0] = (packagePointer[5] & 0x40) >> 6;
WarningFlag[1] = (packagePointer[9] & 0x40) >> 6;
WarningFlag[2] = (packagePointer[13] & 0x40) >> 6;
WarningFlag[3] = (packagePointer[17] & 0x40) >> 6;

if (Index == 0) {
	AnglesCovered = 0;
	for (i = 0; i < 360; i++) {
		if (Distance[i] > 0) AnglesCovered++;
	}

	GoodReadings = 0;
	BadReadings = 0;
}

for (i = 0; i < 4; i++) {
	if (!InvalidFlag[i])
	{
		Distance[Index+i] = packagePointer[4+(i*4)] | ((uint16_t)(packagePointer[5+(i*4)] & 0x3F) << 8);
		GoodReadings++;
	} else {
		Distance[Index+i] = 0;
		BadReadings++;
	}
}

}


void SyncUp(void)
{
	uint8_t i;
	int16_t ch = 0;
	int16_t ch2 = 0;

	//Serial_Buffer_Clear();
	Serial2_Buffer_Clear();


	while (ch != XV11_START_BYTE) {
		while (Serial_Buffer_Get() != XV11_START_BYTE);

		i = XV11_PACKAGE_LENGTH;
		while (i > 0) {
			ch = Serial_Buffer_Get();
			if (ch >= 0) i--;
		}

		// read the rest
		i = XV11_PACKAGE_LENGTH - 1;
		while (i > 0) {
			ch2 = Serial_Buffer_Get();
			if (ch2 >= 0) i--;
		}
	}
}


void LoadPackage(uint8_t * packagePointer)
{
uint8_t i = 0;
uint8_t ch;
int16_t temp;

while (i < XV11_PACKAGE_LENGTH) {
	temp = Serial_Buffer_Get();
	if (temp >= 0) {
		packagePointer[i] = temp;
		i++;
	} else {
		temp = 0;
	}
}
}



uint16_t PackageChecksum(uint8_t * packagePointer)
{
uint8_t i;
uint16_t data[10];
uint16_t checksum;
uint32_t chk32;

// group the data by word, little-endian
for (i = 0; i < 10; i++) {
	data[i] = packagePointer[2*i] | (((uint16_t)packagePointer[2*i+1]) << 8);
}

// compute the checksum on 32 bits
chk32 = 0;
for (i = 0; i < 10; i++) {
	chk32 = (chk32 << 1) + data[i];
}

// return a value wrapped around on 15bits, and truncated to still fit into 15 bits
checksum = (chk32 & 0x7FFF) + ( chk32 >> 15 ); // wrap around to fit into 15 bits
checksum = checksum & 0x7FFF; // truncate to 15 bits
}



void Debug_WriteWords(u16 *word, u16 numWords)
{
	u16 i;
	for (i = 0; i < numWords; i++)
	{
		  SH_SendChar(word[i] & 0x00FF);
		  SH_SendChar((word[i] & 0xFF00) >> 8);
	}
}

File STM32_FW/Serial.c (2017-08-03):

/* Includes ------------------------------------------------------------------*/
#include "stm32f4xx.h"
#include "Serial.h"

#define BUFFER_SIZE	100
uint8_t receiveBuffer[BUFFER_SIZE];
uint16_t bufferWritePos = 0;
uint16_t bufferReadPos = 0;

void Serial_Init(void)
{
	USART_InitTypeDef USART_InitStructure;

	Serial_NVIC_Config();

	  /* USARTx configured as follow:
	        - BaudRate = 115200 baud
	        - Word Length = 8 Bits
	        - One Stop Bit
	        - No parity
	        - Hardware flow control disabled (RTS and CTS signals)
	        - Receive and transmit enabled
	  */
	  USART_InitStructure.USART_BaudRate = 115200;
	  USART_InitStructure.USART_WordLength = USART_WordLength_8b;
	  USART_InitStructure.USART_StopBits = USART_StopBits_1;
	  USART_InitStructure.USART_Parity = USART_Parity_No;
	  USART_InitStructure.USART_HardwareFlowControl = USART_HardwareFlowControl_None;
	  USART_InitStructure.USART_Mode = USART_Mode_Rx | USART_Mode_Tx;

	  GPIO_InitTypeDef GPIO_InitStructure;

	  /* Enable GPIO clock */
	  RCC_AHB1PeriphClockCmd(RCC_AHB1Periph_GPIOA, ENABLE);

	  /* Enable UART clock */
	  // RCC_APB2PeriphClockCmd(RCC_APB2Periph_USART3, ENABLE);
	  RCC_APB2PeriphClockCmd(RCC_APB2Periph_USART1, ENABLE);

	  /* Connect PXx to USARTx_Tx*/
	  GPIO_PinAFConfig(GPIOA, GPIO_PinSource9, GPIO_AF_USART1);

	  /* Connect PXx to USARTx_Rx*/
	  GPIO_PinAFConfig(GPIOA, GPIO_PinSource10, GPIO_AF_USART1);

	  /* Configure USART Tx as alternate function  */
	  GPIO_InitStructure.GPIO_Mode = GPIO_Mode_AF;
	  GPIO_InitStructure.GPIO_Speed = GPIO_Speed_50MHz;

	  GPIO_InitStructure.GPIO_Pin = GPIO_Pin_9;
	  GPIO_InitStructure.GPIO_OType = GPIO_OType_PP;
	  GPIO_InitStructure.GPIO_PuPd = GPIO_PuPd_UP;
	  GPIO_Init(GPIOA, &GPIO_InitStructure);

	  /* Configure USART Rx as alternate function  */
	  GPIO_InitStructure.GPIO_Pin = GPIO_Pin_10;
	  GPIO_InitStructure.GPIO_OType = GPIO_OType_OD;
	  GPIO_InitStructure.GPIO_PuPd = GPIO_PuPd_NOPULL;
	  GPIO_Init(GPIOA, &GPIO_InitStructure);

	  /* USART configuration */
	  USART_Init(USART1, &USART_InitStructure);

	  /* Enable USART */
	  USART_Cmd(USART1, ENABLE);

	  /* Enable interrupt */
	  USART_ITConfig(USART1, USART_IT_RXNE, ENABLE);



	  Serial_Println("");
	  Serial_Println("");
}

void Serial_NVIC_Config(void)
{
    NVIC_InitTypeDef NVIC_InitStructure;

    /* Enable the USART1 Interrupt */
    NVIC_InitStructure.NVIC_IRQChannel = USART1_IRQn;
    NVIC_InitStructure.NVIC_IRQChannelPreemptionPriority = 0;
    NVIC_InitStructure.NVIC_IRQChannelSubPriority = 0;
    NVIC_InitStructure.NVIC_IRQChannelCmd = ENABLE;
    NVIC_Init(&NVIC_InitStructure);
}

/**
  * @brief  This function handles USART1 global interrupt request.
  * @param  None
  * @retval None
  */
void USART1_IRQHandler(void)
{
  char ch;

   if(USART_GetITStatus(USART1, USART_IT_RXNE) != RESET)
   {
     ch = USART_ReceiveData(USART1);       // get received character
 	/*if ((bufferReadPos == bufferWritePos) && (bufferReadPos > (BUFFER_SIZE-100))) {
 		Serial_Buffer_Clear();
 	}
     if (bufferWritePos < BUFFER_SIZE) {
     	receiveBuffer[bufferWritePos] = ch;
     	bufferWritePos++;
     } else {
    	Serial_Buffer_Clear();
     	//while (1); // error - FOR DEBUG
     }*/
     if ((bufferWritePos != (bufferReadPos-1))&&(bufferWritePos < BUFFER_SIZE))
     {
      	receiveBuffer[bufferWritePos] = ch;
      	bufferWritePos++;
     }
   }
}

void Serial_Buffer_Clear(void)
{
	uint16_t i;
	bufferWritePos = 0;
	bufferReadPos = 0;
}

int16_t Serial_Buffer_Get(void)
{
	if (bufferReadPos != bufferWritePos)
	{
		return receiveBuffer[bufferReadPos++];
	} else {
		return -1;
	}
}

uint16_t Serial_Buffer_Count(void)
{
	return (bufferWritePos-bufferReadPos);
}


void Serial_WriteByte(u8 chr)
{
	  USART_SendData(USART1, chr);

	  /* Loop until the end of transmission */
	  while (USART_GetFlagStatus(USART1, USART_FLAG_TC) == RESET) {}
}

void Serial_WriteBytes(u8 *chr, u8 numBytes)
{
	u8 i;
	for (i = 0; i < numBytes; i++)
	{
		  USART_SendData(USART1, chr[i]);

		  /* Loop until the end of transmission */
		  while (USART_GetFlagStatus(USART1, USART_FLAG_TC) == RESET) {}
	}
}

void Serial_WriteWords(u16 *word, u16 numWords)
{
	u16 i;
	for (i = 0; i < numWords; i++)
	{
		  USART_SendData(USART1, (word[i] & 0x00FF));

		  /* Loop until the end of transmission */
		  while (USART_GetFlagStatus(USART1, USART_FLAG_TC) == RESET) {}

		  USART_SendData(USART1, ((word[i] & 0xFF00) >> 8));

		  /* Loop until the end of transmission */
		  while (USART_GetFlagStatus(USART1, USART_FLAG_TC) == RESET) {}
	}
}

void Serial_Print(char *chrBuf)
{
	u8 i = 0;
	while (chrBuf[i] != 0)
	{
		  USART_SendData(USART1, chrBuf[i]);

		  /* Loop until the end of transmission */
		  while (USART_GetFlagStatus(USART1, USART_FLAG_TC) == RESET) {}

		  i++;
	}
}

void Serial_Println(char *chrBuf)
{
	u8 i = 0;
	while (chrBuf[i] != 0)
	{
		  USART_SendData(USART1, chrBuf[i]);
		  /* Loop until the end of transmission */
		  while(USART_GetFlagStatus(USART1, USART_FLAG_TXE) == RESET) {}

		  i++;
	}

	USART_SendData(USART1, 0x0A);
	/* Loop until the end of transmission */
	while (USART_GetFlagStatus(USART1, USART_FLAG_TC) == RESET) {}

	USART_SendData(USART1, 0x0D);
	/* Loop until the end of transmission */
	while (USART_GetFlagStatus(USART1, USART_FLAG_TC) == RESET) {}
}

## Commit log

2017-08-03 feature freeze
    [8mm spacer.ipt, 8mm_spacer_0.stl, Lidar.0006.ipt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]
2017-08-03 eagle pcb files
    [Motherboard_STM32F405RG.brd, Motherboard_STM32F405RG.sch, Motherboard_STM32F405RG_r1.brd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]
2017-08-07 README added
    clean up
    [8mm_spacer_0.stl, Lidar.0006.ipt, Lidar_v2.0003.ipt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]
2017-08-07 Wiring image
    readme update

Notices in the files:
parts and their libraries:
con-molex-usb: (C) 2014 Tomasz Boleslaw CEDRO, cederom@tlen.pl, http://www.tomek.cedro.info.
